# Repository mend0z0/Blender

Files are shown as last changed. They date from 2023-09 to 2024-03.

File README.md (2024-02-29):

## Latest update

``
Assembling the board, and working on the firmware...
``

# Blender

The Blender project's purpose is to extract digitalized sound characteristics like amplitude and frequency, which are transferring through the S/PDIF protocol, and display the amplitude of different frequencies by the dominant color of the input VGA received signal. So the base color will be determined by VGA input, and a spectrum of that color will be displayed over/on the DMX/WS2812 chip. Also, the specification of the sound will be displayed on an OLED, and the sound will be played by a chip that has an integrated DAC in it. The data to DAC will be transferred via the I2S protocol.

## Category

__Digital Signal Processing (DSP)__

## Features

- Battery Powered
- Can be installed in-line.
- On board speaker and WS2812 for troubleshooting.

## Technology

### Hardware

- **MCU:** STM32F446RCT6
- **Connection:** S/PDIF, VGA, DMX, I2S, Addressable LEDs (PWM)
- **PCB Layers:** 4Layer/s (None-controlled Impedance)
- **CAD:** KiCAD

### Firmware

- **OS:** FreeRTOS
- **Programming Language:** C
- **IDE:** STM32CubeIDE

### Mechanical

- **CAD:** Solid Edge
- **Manufacturing Method:** 3D Printing

## Block Diagram

SystemDesign

## Glamour Shots

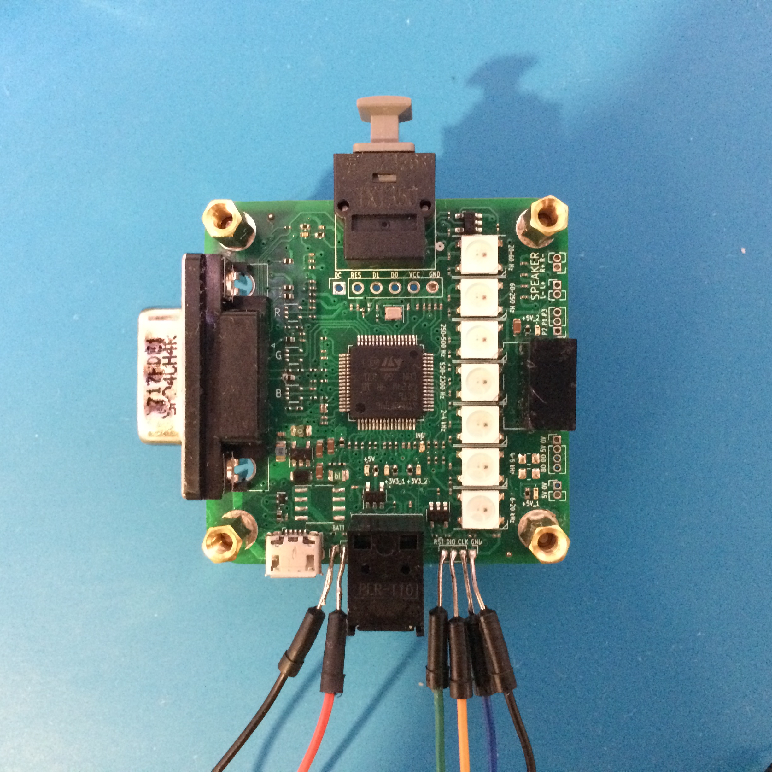
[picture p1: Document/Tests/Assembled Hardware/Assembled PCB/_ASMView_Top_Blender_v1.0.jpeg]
_ASMView_Top
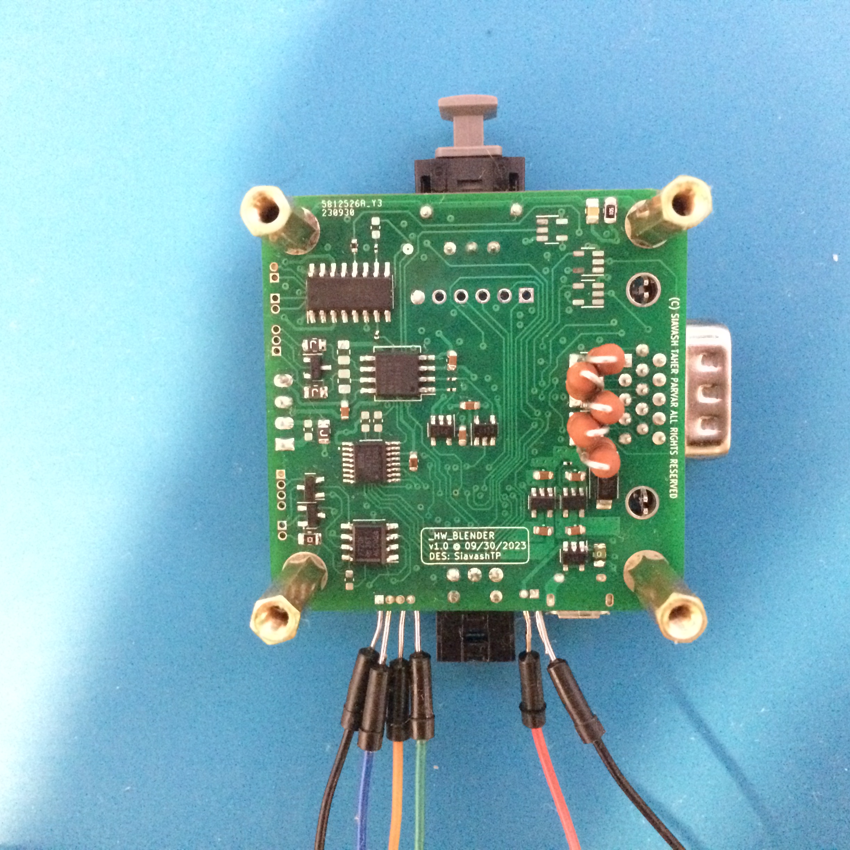
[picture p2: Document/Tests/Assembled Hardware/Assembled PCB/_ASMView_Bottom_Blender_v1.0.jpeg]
_ASMView_Bottom
|  |  | _3DModelView_Blender_v1-2024mmdd | _AppView_Blender_v1-2024mmdd |
|:--:| :--:| :--:| :--: |
| PCB Top View | PCB Bottom View | Enclosure View | Application View |

### Final Device

_BLENDER

## Demo

Not ready yet...

## Author

- [@Siavash Taher Parvar](https://www.linkedin.com/in/mend0z0)

## Support

- [Support Link](https://github.com/sponsors/mend0z0)

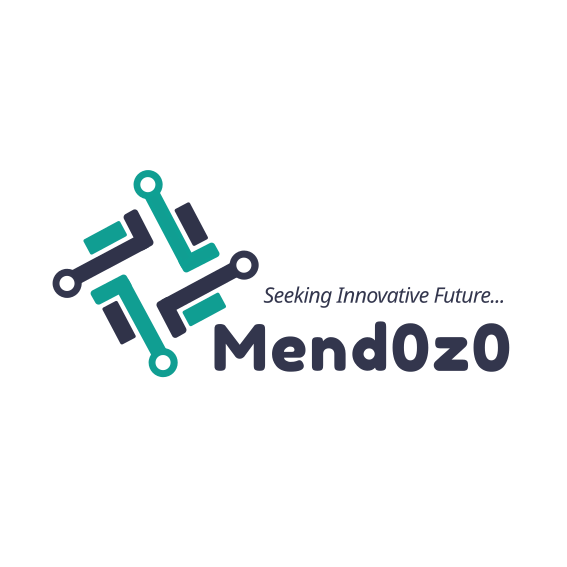
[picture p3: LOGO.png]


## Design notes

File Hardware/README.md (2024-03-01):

## _SUB_Hardware_Blender

- What is this board? This board is the main board which gets the inputs and runs some digital processing and will feed the the output devices.
- How will this board communicate? The current version will determine the output by the input signals.

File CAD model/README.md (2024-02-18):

# _SUB_Mechanical_Project

- What is this Mechanical Design? 
- Where would be located?

## Features

- __Material:__ PLA
- __Overall Dimensions:__
- __Manufacturing Method:__ 3D Printer

### Mechanical CAD View (Latest Version)

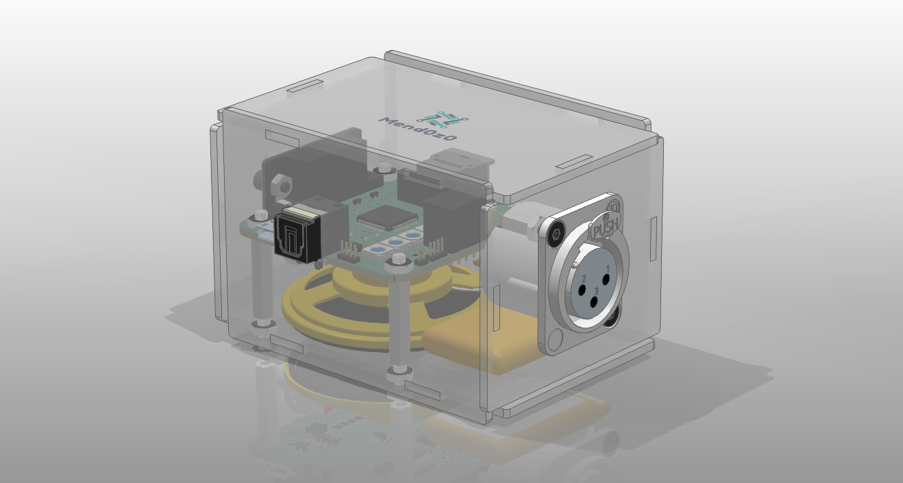
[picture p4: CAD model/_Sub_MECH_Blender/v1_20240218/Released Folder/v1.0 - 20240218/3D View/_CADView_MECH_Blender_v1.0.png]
_CADView_MECH_v1-20240218


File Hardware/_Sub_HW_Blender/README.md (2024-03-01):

## Version History Roadmap

- __v1_20230918 :__ 
	- It's the first version.

| 3D View - v1.0 | Features |
|:--:|:--:|
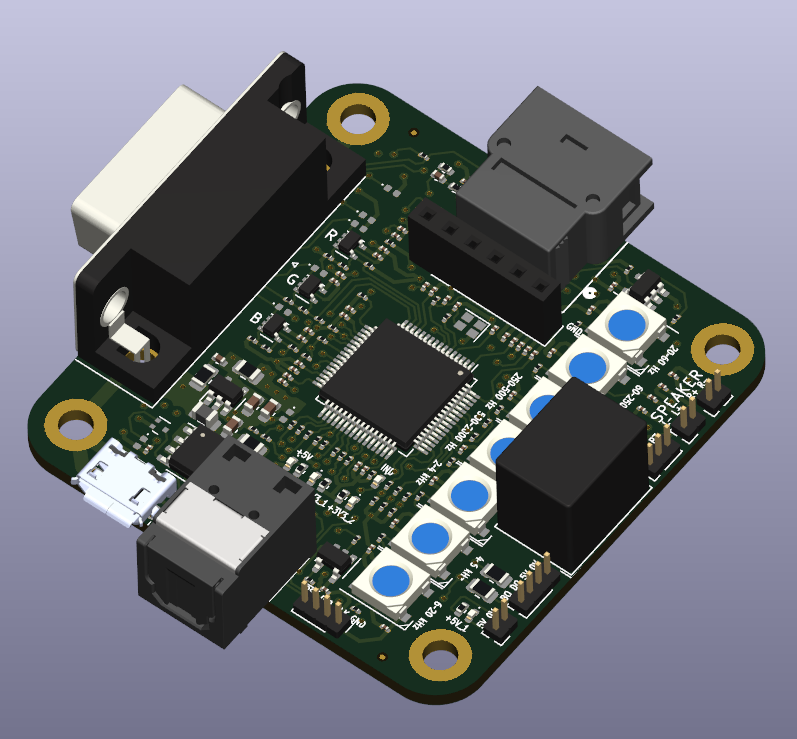
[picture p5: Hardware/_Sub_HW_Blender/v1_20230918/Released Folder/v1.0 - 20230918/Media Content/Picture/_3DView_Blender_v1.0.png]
_3DView_v1_20230918
|  | <br><P align="left">__MCU :__ STM32F446RCT6</br><br align="left">__Inputs :__ VGA Input, S/PDIF</br><br align="left">__Outputs :__ DMX, WS2812, SPEAKER, Display (OLED)</br><br align="left">__Board Osc. Freq. :__ 160 MHz</br><br align="left">__Working Voltage :__ 3.3 VDC </br><br align="left">__Current Consumption :__  TBD</br><br align="left">__Board Dimensions :__ 50*50 mm</br> |

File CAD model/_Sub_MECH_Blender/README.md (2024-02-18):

# Version History

A brief description of this version history belongs to what project

## Roadmap

- __v1_20240218 :__ It's the first version.

### Mechanical CAD View (Latest Release)

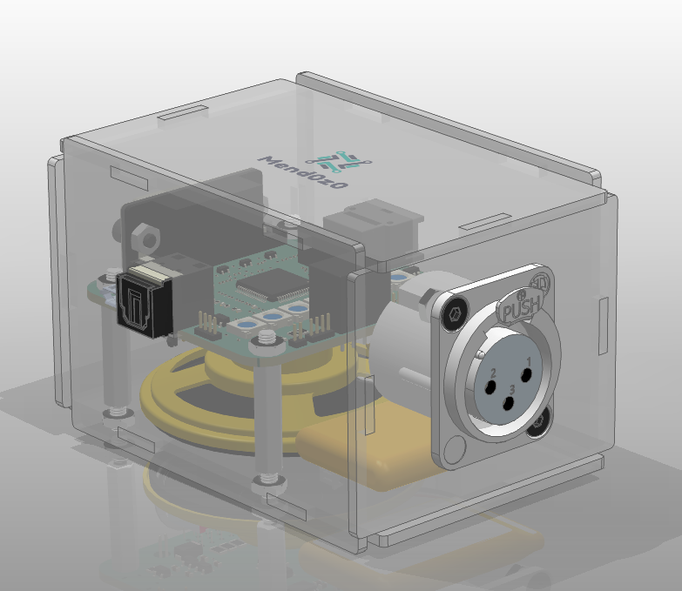
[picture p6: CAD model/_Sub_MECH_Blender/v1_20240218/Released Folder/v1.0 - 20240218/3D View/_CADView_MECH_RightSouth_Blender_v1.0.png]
_CADView_MECH_RightSouth_Blender_v1_20240218


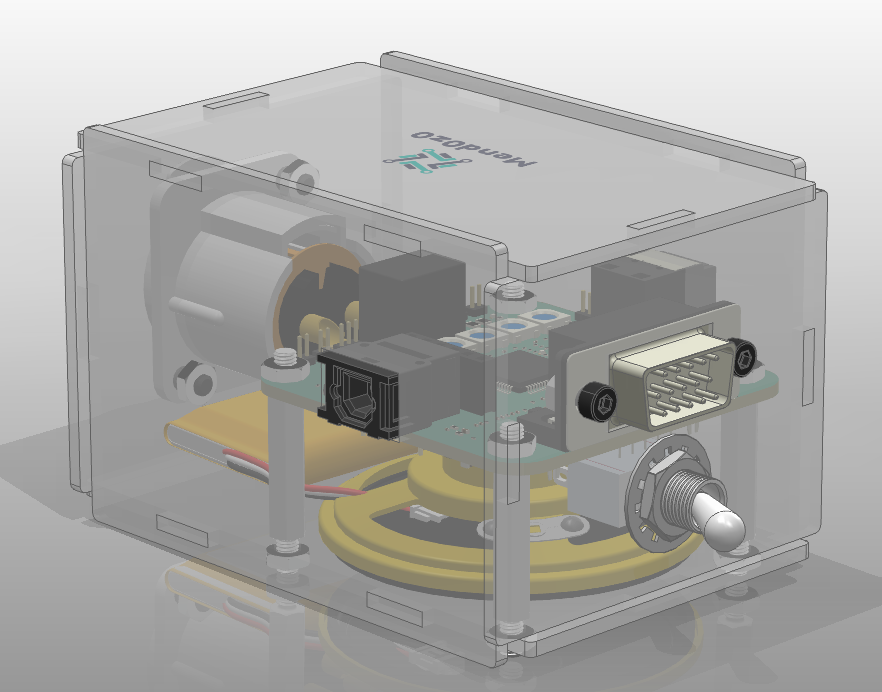
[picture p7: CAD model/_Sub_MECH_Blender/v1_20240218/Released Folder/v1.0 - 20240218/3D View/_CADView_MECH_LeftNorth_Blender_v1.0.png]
_CADView_MECH_Blender_LeftNorth_v1_20240218


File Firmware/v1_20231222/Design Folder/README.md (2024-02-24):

# TODO List

Blender firmware project todo list.

## Tasks

- #### MUST DO (List the works that proper working of project depends on these tasks):
    - Drawing peripheral functions block diagram (CLK, GPIO, TIMER 0, TIMER 1, TIMER 2, TIMER 3, I2C, DMA, RTC, SPDIF, I2S, ADC, UART, WDT)
    - 
    - Drawing each module/device API/Init functions block diagram (Ind LED, SSD1306, Toslink, WS2812, DMX, VGA, PAM8003, PCM1754)
    - Writing C code for the drawn block diagram
    - Writing C code for the ISR
    - Writing C code for the modules/devices
    - Drawing a test scenario for connected modules/devices
    - Writing C code the test scenario block diagram
    - Drawing block diagram for main super-loop
    - Writing C code for the main super-loop block diagram
    - 
    - 
    - Doing UART + DMA driver
    - Doing DMX
    - Doing TIM3 + DMA
    - Doing WS2812
    - Doing I2C + DMA
    - Doing SSD1306 Driver
    - Doing FreeRTOS
    - 
    - 
    - 
    - 
    - 
    -
    - 
- #### Important (List the works that efficient and optimized functionality of project depends on these tasks):
    - Configuring TIM5 for reading system clock frequency and displaying on OLED (Next revision)
    -
    - 
- #### General (List tasks that are good to be done but the functionality of project doesn't depend on these):
    - 
    -
    -

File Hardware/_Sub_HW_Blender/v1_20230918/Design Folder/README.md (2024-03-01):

## TODO list

Blender hardware project v1 todo list.

## Tasks

- #### MUST DO (List the works that proper working of project depends on these tasks):
    - Correcting the power ports labels.?
    - Labeling correction (Correcting that @ shit in the info label on the PCB). (Next revision)
    - Checking circuitry and adding information
    - Adding Mechanical parts (Wire, XLR connector, inline connector for ws2812, OLED, some standoffs, screws, and enclosure, 2 x speaker).
    - Doing the Power sequence analysis
    - Exporting output files
    - Adding info to Coverpage
    - Correcting the information for each page
    - 
    - Very important, changing the MOSFET part number to SI4435FDY-T1-GE3 (https://www.digikey.ca/en/products/detail/vishay-siliconix/SI4435FDY-T1-GE3/7566600). (Next revision)
    - Very important, changing the MOSFET gate circuit to a pulldown resistor and a PNP transistor. (Next revision)
    - Modifying prog pins according to the programmer. (Next revision)
    - Placing the logo in a better and visible spot. (Next revision)
    - Remove all the resistors for WS2812 (or make it like 10ohm or 0ohm)
    - 
    - 
    - 
- #### Important (List the works that efficient and optimized functionality of project depends on these tasks):
    - Sizing up the packages to 0603. (Next revision)
    - Adding the missing 3D parts. (Next revision)
    - Adding on/off switch. (Next revision)
    - Adding test points for voltages. (Next revision)
    -
    - 
- #### General (List tasks that are good to be done but the functionality of project doesn't depend on these):
    - 
    -
    -

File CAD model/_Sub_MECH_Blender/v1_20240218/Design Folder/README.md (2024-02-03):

# TODO list

A brief description of this todo list belongs to what project

## Tasks

- #### MUST to DO (List the works that proper working of project depends on these tasks):
    - Add a screw for
    - Add a USB slot
    - Add a power button (push button)
    - Add the logo in a way that would be engraved... (looking for how to add a picture as an object so I can give it depth
    - Add a slot for WS2812
    - Opening an output folder (one output for laser cut)
    - Add a tolerance to the openings
    - Make the edges curvy..
    - adding a switch to enclosure
    - 
    - 
    - 
- #### Important (List the works that efficient and optimized functionality of project depends on these tasks):
    - 
    -
    - 
- #### General (List tasks that are good to be done but the functionality of project doesn't depend on these):
    - 
    -
    -

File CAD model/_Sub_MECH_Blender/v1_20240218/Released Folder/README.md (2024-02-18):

# Revision History

A brief description of this revision history belongs to what project

## Roadmap

- #### __v1.0_20240218 :__ 
    - List the changes or modification that have been applied in this revision.

### Mechanical CAD View

_CADView_MECH_v1.0_20240218

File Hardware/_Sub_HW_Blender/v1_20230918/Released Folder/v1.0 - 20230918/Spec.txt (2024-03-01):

#Board Spec
- __MCU :__ STM32F446RCT6
- __Inputs :__ VGA Input, S/PDIF
- __Outputs :__ DMX, WS2812, SPEAKER, Display (OLED) 
- __Board Osc. Freq. :__ 160 MHz
- __Working Voltage :__ 3.3 VDC
- __Current Consumption :__  TBD

#Board Statistics
- __Component Total: 217
- __Total Pad: 858
- __Total Vias: 146 
- __Board Layers: 4 Layers (Non-impedance Controlled)
- __Board Dimensions :__ 49.66 * 49.66 mm2

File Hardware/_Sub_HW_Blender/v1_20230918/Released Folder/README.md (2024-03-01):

## Revision History Roadmap

- #### __v1.0_20230918 :__ 
	The first release.

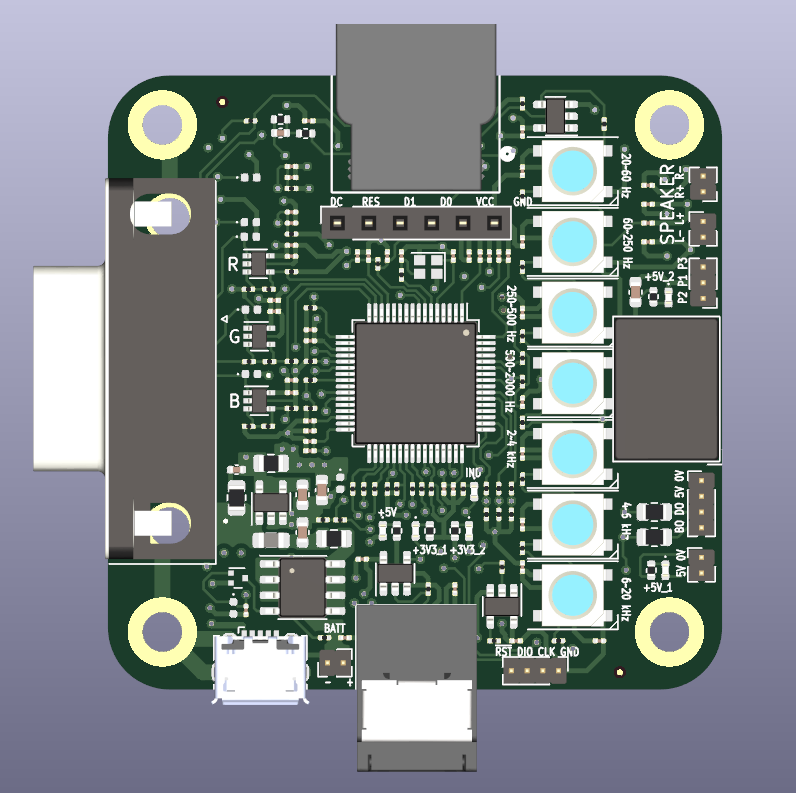
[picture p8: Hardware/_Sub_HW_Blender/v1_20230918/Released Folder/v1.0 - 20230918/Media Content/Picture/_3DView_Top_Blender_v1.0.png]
_3DView_Top_Blender_v1.0
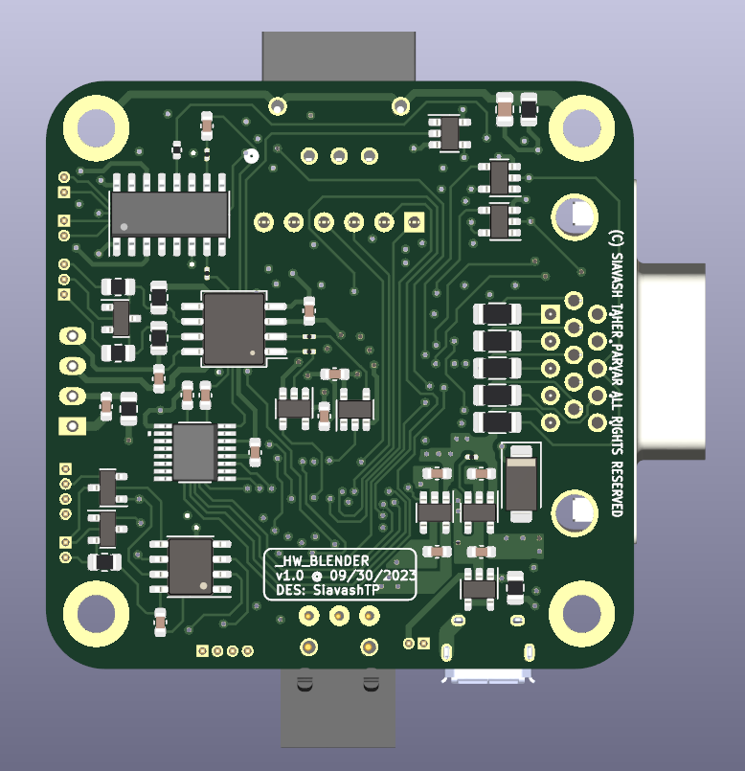
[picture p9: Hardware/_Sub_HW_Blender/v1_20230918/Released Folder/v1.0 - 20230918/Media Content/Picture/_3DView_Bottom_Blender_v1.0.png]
_3DView_Bottom_Blender_v1.0
| Hardware | |  |
|:--:|:--:|:--:|
| Block Diagram | Top Layer | Bottom Layer |

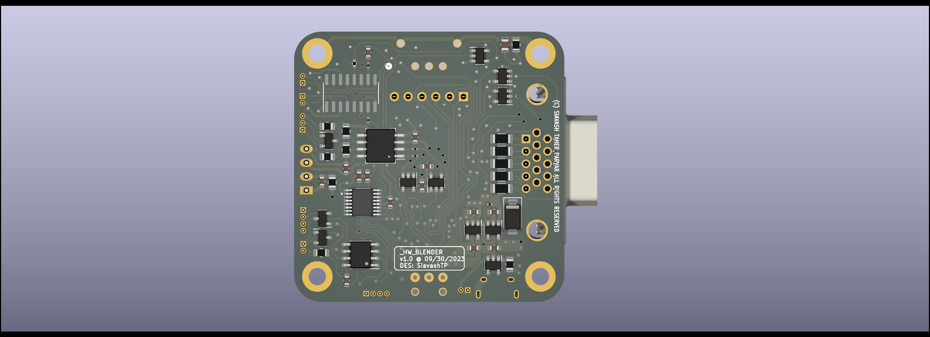
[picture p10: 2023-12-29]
Hardware/_Sub_HW_Blender/v1_20230918/Design Folder/_HW_Blender/Output files/3D View/_3DView_Bottom_Blender_v1.0.png

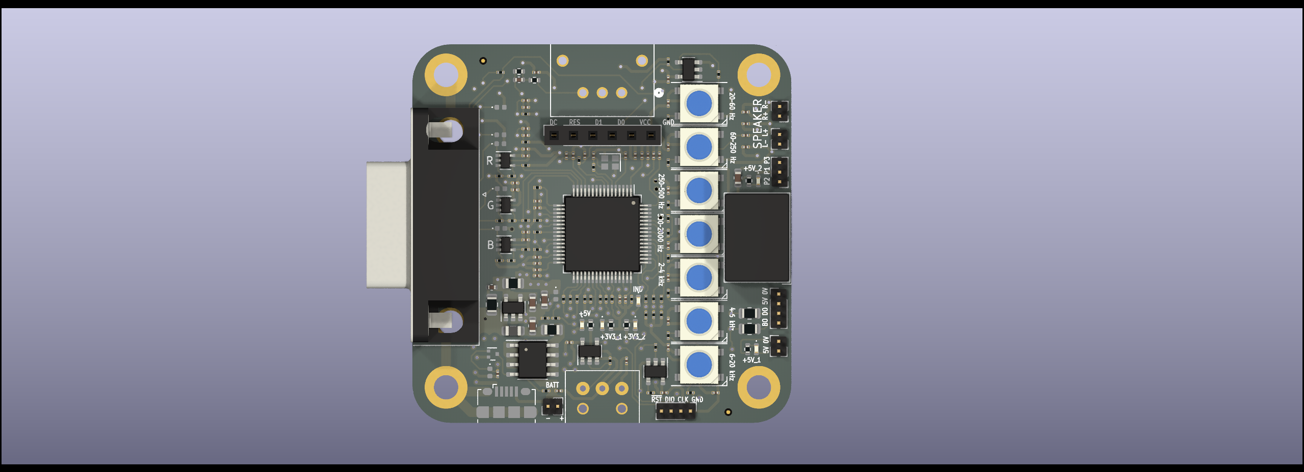
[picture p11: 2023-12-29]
Hardware/_Sub_HW_Blender/v1_20230918/Design Folder/_HW_Blender/Output files/3D View/_3DView_Top_Blender_v1.0.png

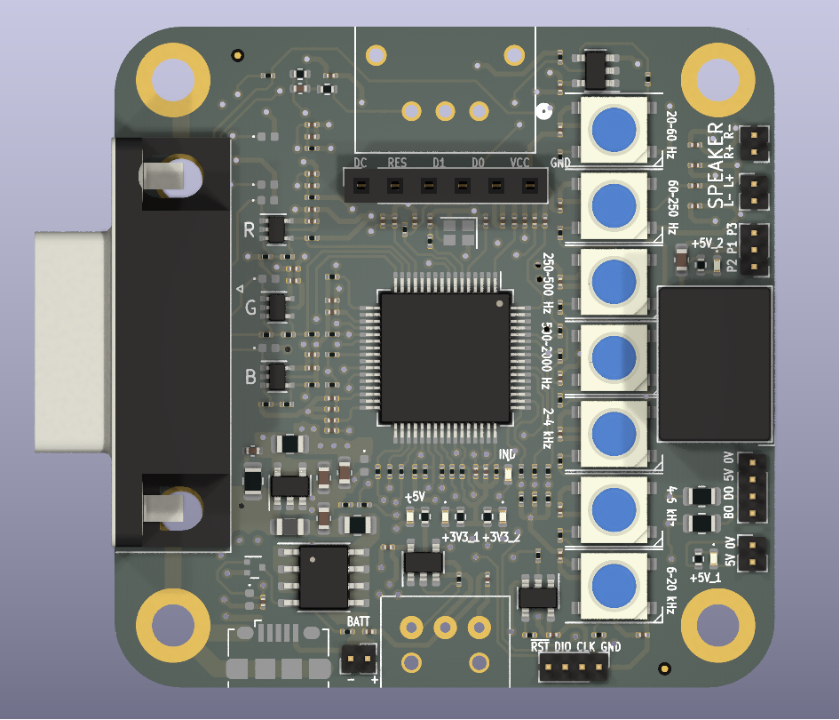
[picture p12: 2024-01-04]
Hardware/_Sub_HW_Blender/v1_20230918/Design Folder/_HW_Blender/Output files/3D View/_3DView_Top_Blender_v1.0 - Copy.png

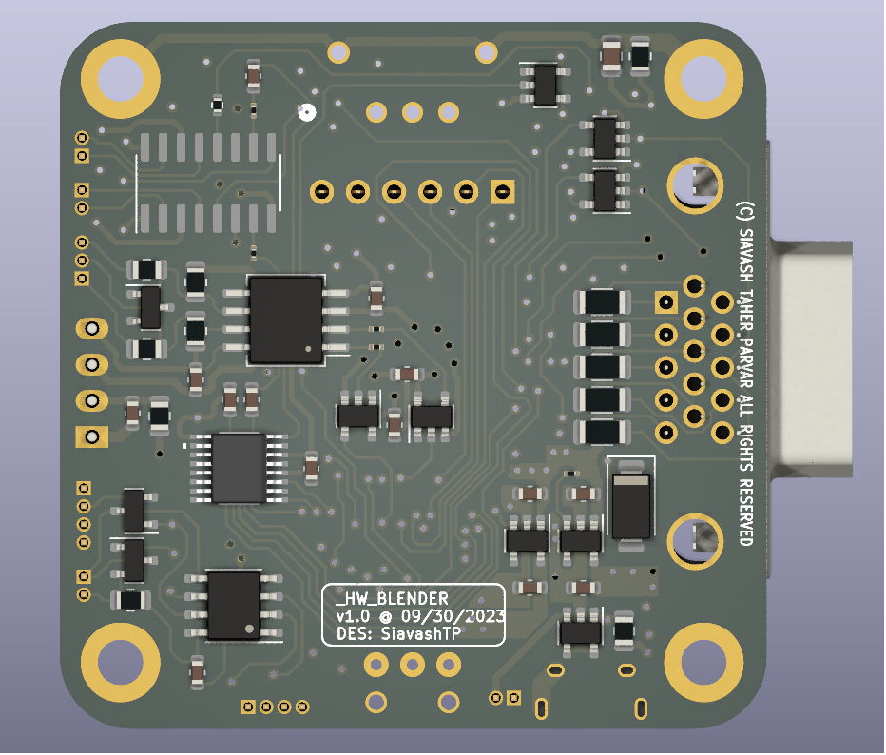
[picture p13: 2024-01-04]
Hardware/_Sub_HW_Blender/v1_20230918/Design Folder/_HW_Blender/Output files/3D View/_3DView_Bottom_Blender_v1.0 - Copy.png

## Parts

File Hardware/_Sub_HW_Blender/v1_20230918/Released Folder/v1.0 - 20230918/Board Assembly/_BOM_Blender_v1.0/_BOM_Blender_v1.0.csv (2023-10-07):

Id | Designator | Footprint | Quantity | Designation | Supplier and ref
1 | R615,R1008,R701,R1003,R1005 | R_0402_1005Metric | 5 | 470R_1/16W
2 | X301 | Crystal_SMD_2016-4Pin_2.0x1.6mm | 1 | 16MHz/10ppm
3 | R812,R814,R901,R815,R813,R902,R403,R1002 | R_0201_0603Metric | 8 | 4K7R_1/20W
4 | R506,R509,R303 | R_0201_0603Metric | 3 | 49R9_1/20W
5 | R611,R612 | R_0805_2012Metric | 2 | 1KR_1/8W
6 | R1302,R1201,R1202,R1301,R1402,R1401 | R_0201_0603Metric | 6 | 47KR_1/20W
7 | J501 | DSUB-15-HD_Male_Horizontal_P2.29x1.98mm_EdgePinOffset3.03mm_Housed_MountingHolesOffset4.94mm | 1 | DE-15_MALE_RA
8 | C1401,C808,C1201,C609,C601,C604,C1301,C607,C501,C805,C309,C806,C605,C608,C603,C611,C308,C503,C606,C602 | C_0201_0603Metric | 20 | 2u2F/6V3
9 | D1002,D503,D505,D502,D1003,D501,D504 | D_0402_1005Metric | 7 | GG040205100N2P
10 | J1002 | USB_Micro-B_Amphenol_10118194_Horizontal | 1 | MICRO B USB_RA
11 | C1402,C305,C311,C502,C403,C1202,C402,C1302,C307,C317,C315,C404,C504,C313 | C_0201_0603Metric | 14 | 100nF/6V3
12 | D604,D603,D605,D601,D607,D606,D602 | LED_WS2812B_PLCC4_5.0x5.0mm_P3.2mm | 7 | WS2812B
13 | J901 | PinSocket_1x06_P2.54mm_Vertical | 1 | RCPT_6POS_2.54MM_VERT
14 | C303,C302 | C_0201_0603Metric | 2 | 12pF/50V
15 | R607,R810,R806,R804,R903,R606,R808,R1006,R803,R614,R608,R603,R610,R605,R602,R601,R304,R613,R904,R809,R811,R807,R704,R705,R805 | R_0201_0603Metric | 25 | 100R_1/20W
16 | J301,J602 | PinHeader_1x04_P1.27mm_Vertical | 2 | RCPT_4POS_1.27MM
17 | U301 | LQFP-64_10x10mm_P0.5mm | 1 | STM32F446RCT6TR
18 | J402 | TOTX1350_TOS | 1 | TOTX1350(F)
19 | R604,R404,R801,R1007,R504,R1203,R1403,R702,R302,R507,R1303,R301,R1004 | R_0201_0603Metric | 13 | 10KR_1/20W
20 | C306,C310,C312,C1006,C807,C1005,C314,C304,C316,C301,C901 | C_0201_0603Metric | 11 | 1uF/6V3
21 | LED1002,LED1003 | LED_0402_1005Metric | 2 | AMBER
22 | J701 | PinHeader_1x03_P1.27mm_Vertical | 1 | RCPT_3POS_1.27MM
23 | C401,C1001 | C_0402_1005Metric | 2 | 680pF_50V
24 | C1003,C1002,C702,C1004,C801,C1009,C610,C1007,C1010,C804,C1008,C803,C802,C705,C701,C703,C704,C706 | C_0603_1608Metric | 18 | 10uF/16V
25 | LED601,LED1001,LED701 | LED_0402_1005Metric | 3 | GREEN
26 | U701 | Converter_DCDC_RECOM_R-78S-0.1_THT | 1 | 1S4E_0505S1.5U
27 | J1001,J802,J601,J801 | PinHeader_1x02_P1.27mm_Vertical | 4 | MHDR_2POS_1.27MM_VERT
28 | Q1002 | SOT-723 | 1 | RN1130MFV,L3F
29 | R401 | R_0402_1005Metric | 1 | 330R_1/16W
30 | LED301 | LED_0402_1005Metric | 1 | RED
31 | U1301,U1201,U1401 | SOT-353_SC-70-5 | 3 | MIC920YC5-TR
32 | R1001 | R_0805_2012Metric | 1 | 4R7_1/4W
33 | U603,U401,U601,U702,U501,U402,U502,U705 | SOT-23-5 | 8 | SN74LVC1G17DBVR
34 | RV1001,RV1002 | Fuse_0805_2012Metric | 2 | PTC_500mA
35 | U1001 | SOT-23-5 | 1 | TPS613222ADBVR
36 | J401 | PLR237T10BK | 1 | PLR237/T10BK
37 | F1001 | Fuse_0805_2012Metric | 1 | 0ZCK0100FF2E
38 | R402,R802 | R_0402_1005Metric | 2 | 100R_1/10W
39 | L1001 | L_0805_2012Metric | 1 | 2u2H_2A
40 | FD1102,FD1101 | Fiducial_0.5mm_Mask1mm | 2 | ~
41 | Q1001 | SO-8_3.9x4.9mm_P1.27mm | 1 | SI4455DY-T1-GE3
42 | U703 | SOT-23 | 1 | CDSOT23-SM712
43 | R501,R502,R508,R503,R505 | R_1206_3216Metric | 5 | 75R_2W
44 | D1001 | D_SMA | 1 | SK510A-LTP
45 | R706,R703 | R_0805_2012Metric | 2 | 680R_1/8W
46 | F703,F702,F701 | Fuse_0805_2012Metric | 3 | 0805L010/24YR
47 | U1003 | SOT-23-5 | 1 | MCP73811T-420I/OT
48 | U605,U604 | SOT-23 | 2 | DLPT05A-7
49 | C1101 | C_0805_2012Metric | 1 | 1nF_500V
50 | U801 | SOP-16_3.9x9.9mm_P1.27mm | 1 | PAM8003DR
51 | R609 | R_0805_2012Metric | 1 | 100R_1/8W
52 | U1002,U1004 | SOT-23-5 | 2 | TLV74033PDBVR
53 | U802 | DBQ16 | 1 | PCM1754DBQR
54 | U602 | SOIC-8_3.9x4.9mm_P1.27mm | 1 | ISO7720FDR
55 | R1101 | R_0805_2012Metric | 1 | 1MR_1/2W
56 | U704 | SO-8_5.3x6.2mm_P1.27mm | 1 | MAX22028AWA+

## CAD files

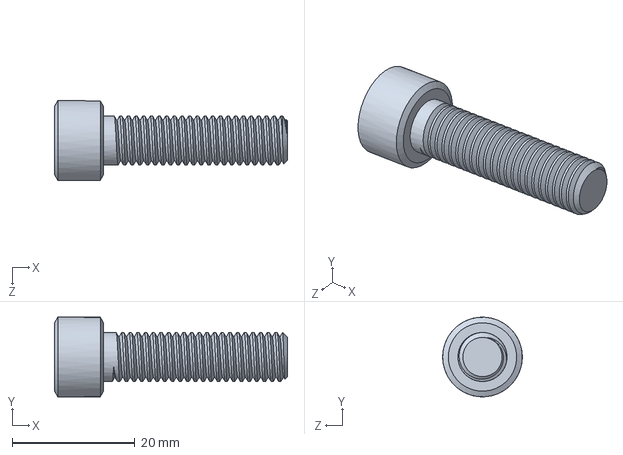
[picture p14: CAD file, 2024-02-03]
CAD model/_Sub_MECH_Blender/v1_20240218/Design Folder/_MECH_Blender/Parts/TORNILLO DIN-912-2014.SLDPRT
38.0 x 13.0 x 13.0 mm

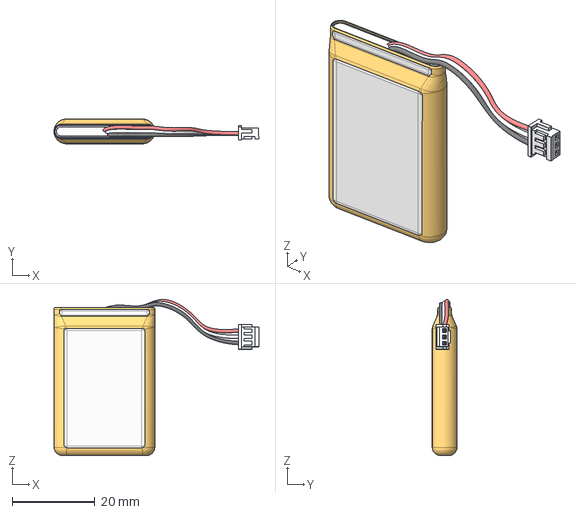
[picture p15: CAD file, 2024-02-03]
CAD model/_Sub_MECH_Blender/v1_20240218/Design Folder/_MECH_Blender/STEP Files/3.7v li-ion 500mah Battery.step
49.6 x 6.05 x 37.8 mm

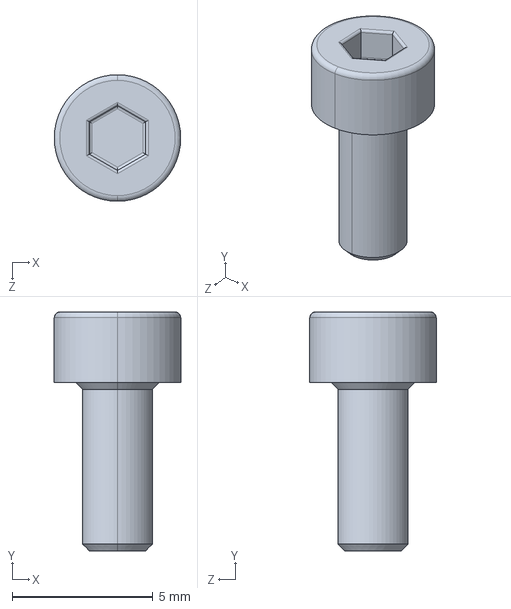
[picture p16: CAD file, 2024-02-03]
CAD model/_Sub_MECH_Blender/v1_20240218/Design Folder/_MECH_Blender/STEP Files/User Library-Dinp912.step
4.50 x 8.50 x 4.50 mm

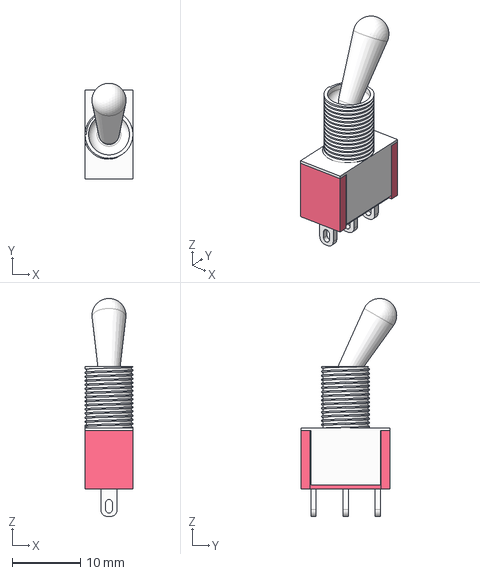
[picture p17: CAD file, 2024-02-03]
CAD model/_Sub_MECH_Blender/v1_20240218/Design Folder/_MECH_Blender/STEP Files/toggle switch.step
7.00 x 14.0 x 32.0 mm

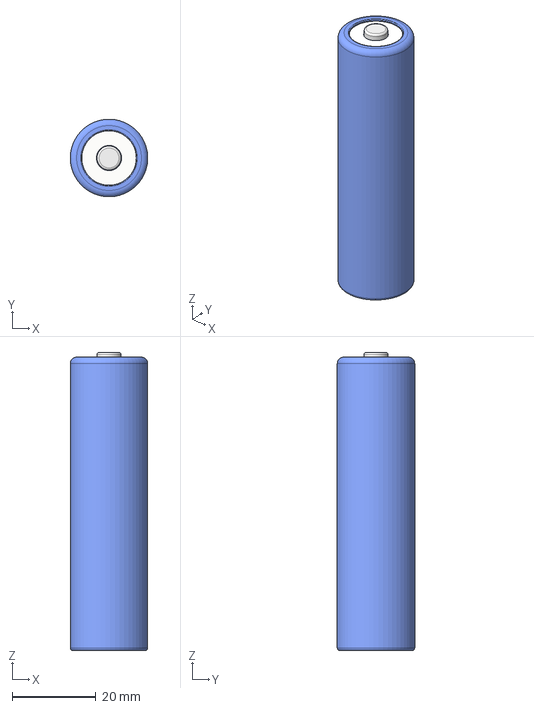
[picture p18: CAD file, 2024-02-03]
CAD model/_Sub_MECH_Blender/v1_20240218/Design Folder/_MECH_Blender/STEP Files/Profuse - 18650.step
18.5 x 18.5 x 71.1 mm

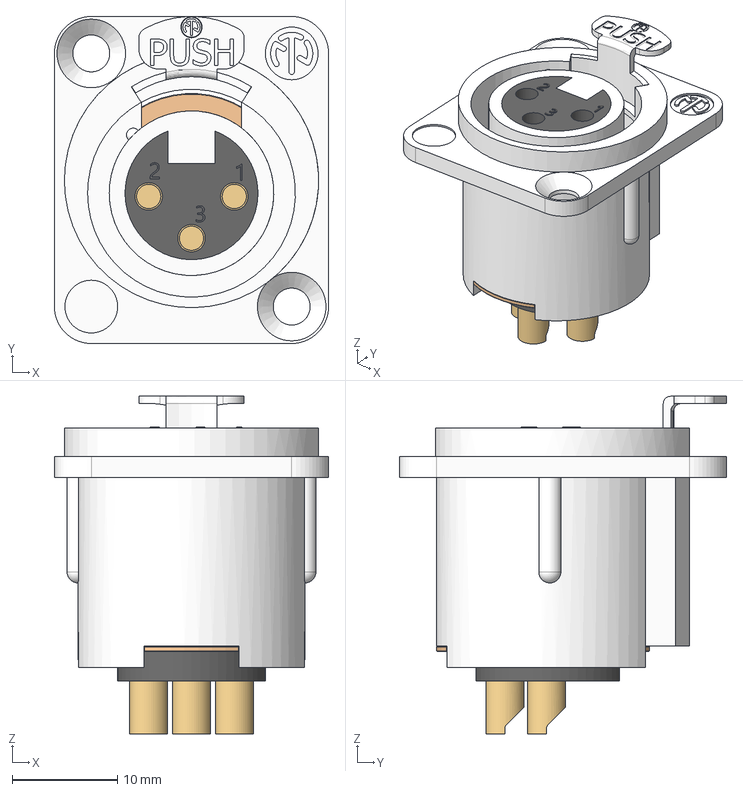
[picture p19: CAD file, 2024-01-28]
CAD model/_Sub_MECH_Blender/v1_20240218/Design Folder/_MECH_Blender/STEP Files/NC3FD-LX.stp
26.0 x 31.0 x 32.0 mm
5-POLE
BACK LOCK
PUSH PIN
PIN x 3

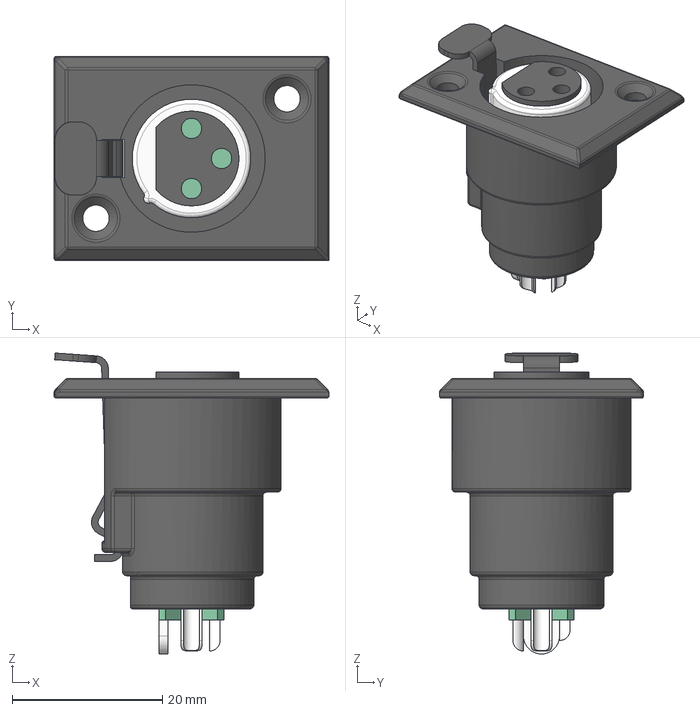
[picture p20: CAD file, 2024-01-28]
CAD model/_Sub_MECH_Blender/v1_20240218/Design Folder/_MECH_Blender/STEP Files/Connector, XLR3, Female, Chassis - Switchcraft-D3FB.stp
36.5 x 27.1 x 40.0 mm

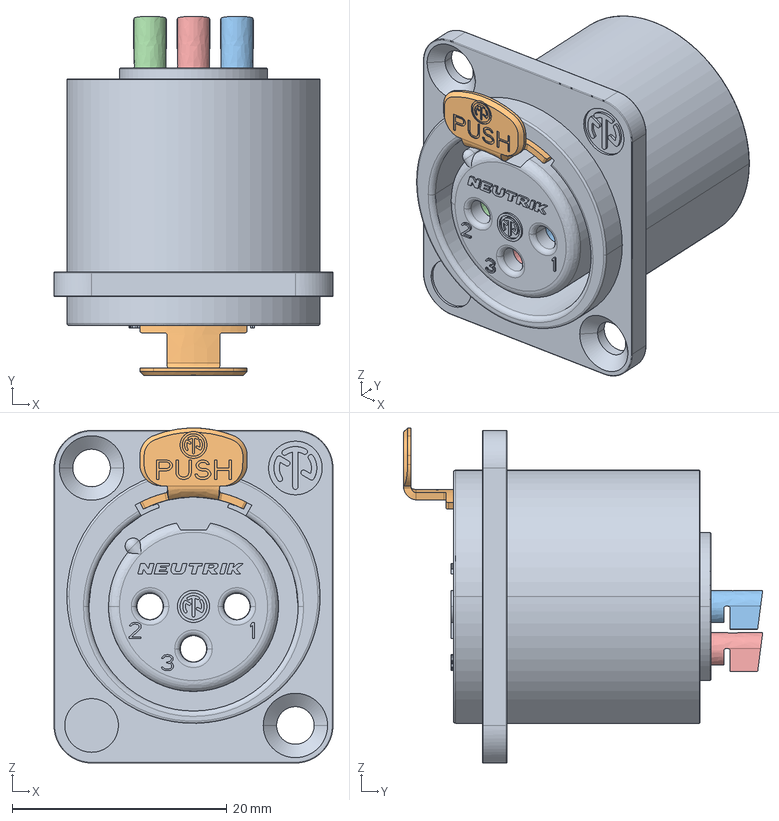
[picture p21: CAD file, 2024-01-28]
CAD model/_Sub_MECH_Blender/v1_20240218/Design Folder/_MECH_Blender/STEP Files/NC3FD-LX_01-GC-STEP.stp
26.0 x 33.5 x 31.2 mm

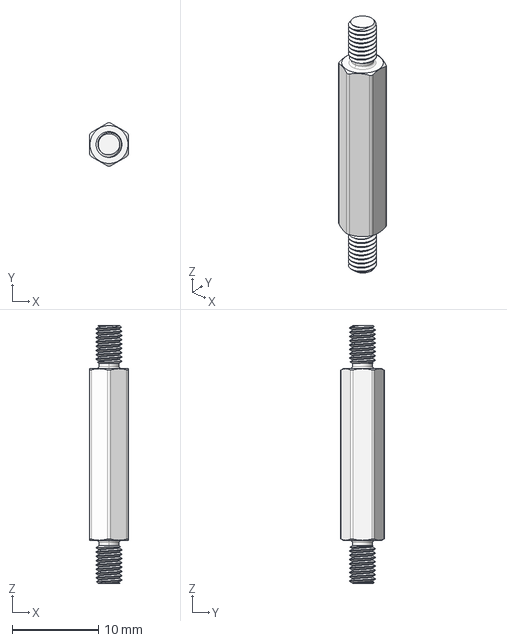
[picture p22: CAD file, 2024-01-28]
CAD model/_Sub_MECH_Blender/v1_20240218/Design Folder/_MECH_Blender/STEP Files/Standoff M3 M-M H 20mm.stp
4.50 x 5.08 x 30.0 mm

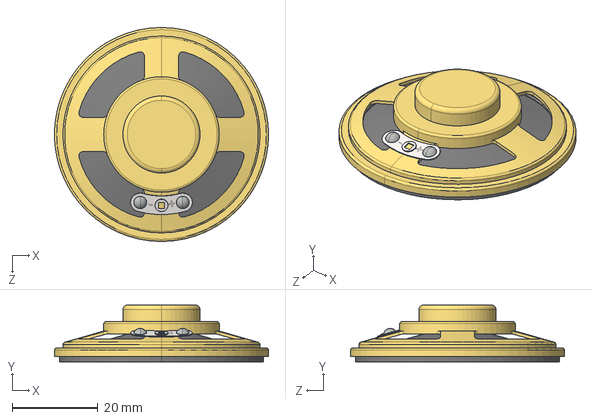
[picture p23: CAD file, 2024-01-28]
CAD model/_Sub_MECH_Blender/v1_20240218/Design Folder/_MECH_Blender/STEP Files/Speaker, dia 50mm.STEP
50.0 x 13.3 x 50.0 mm

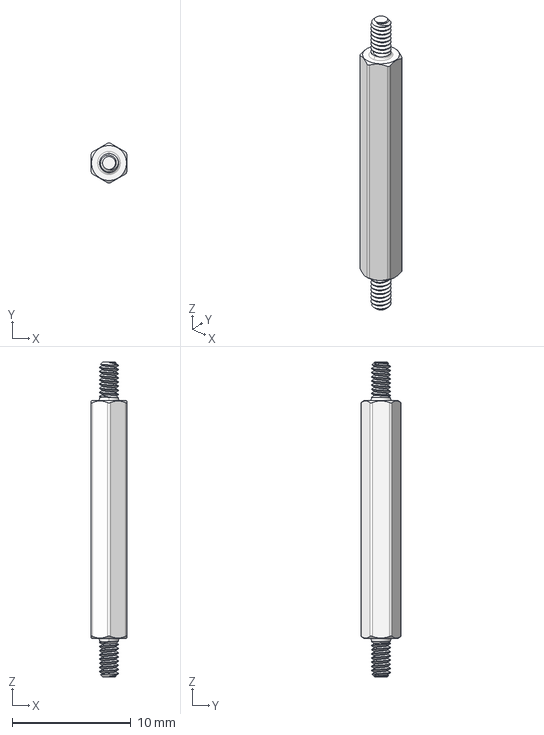
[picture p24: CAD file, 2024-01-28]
CAD model/_Sub_MECH_Blender/v1_20240218/Design Folder/_MECH_Blender/STEP Files/Standoff M1.6 M-M H 20mm.stp
3.00 x 3.39 x 26.5 mm

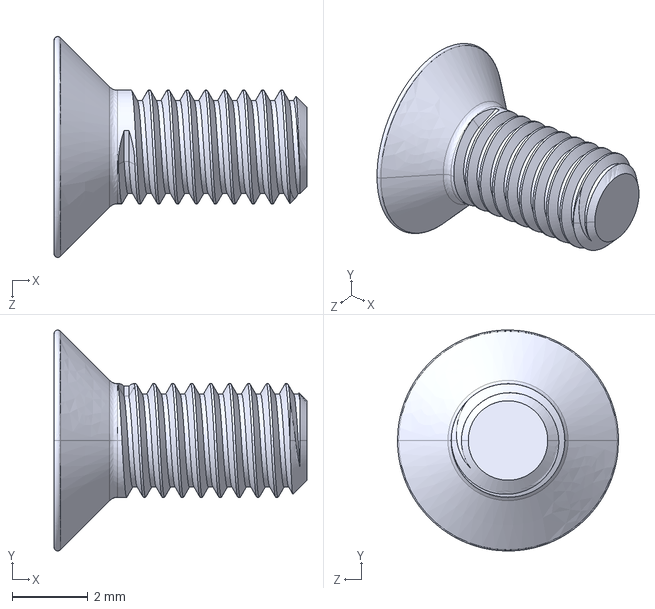
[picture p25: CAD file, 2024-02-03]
CAD model/_Sub_MECH_Blender/v1_20240218/Design Folder/_MECH_Blender/Parts/M3_Countersunk_Screw_5.IGS
6.68 x 5.84 x 5.84 mm

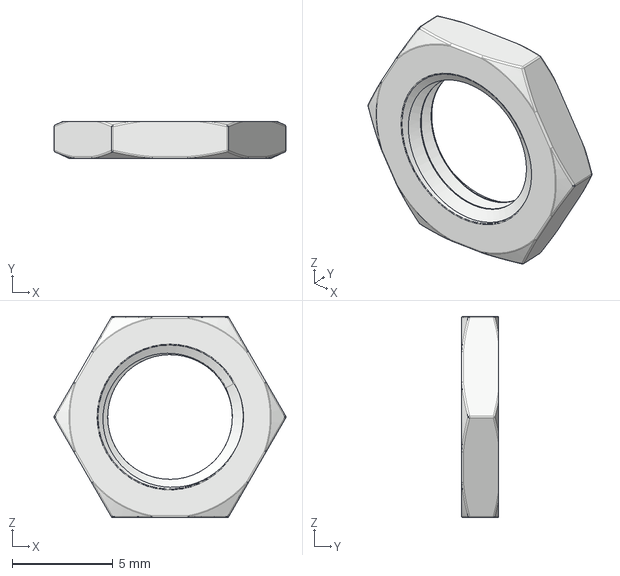
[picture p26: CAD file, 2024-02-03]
CAD model/_Sub_MECH_Blender/v1_20240218/Design Folder/_MECH_Blender/STEP Files/Nut M7x075.stp
11.5 x 1.85 x 10.0 mm

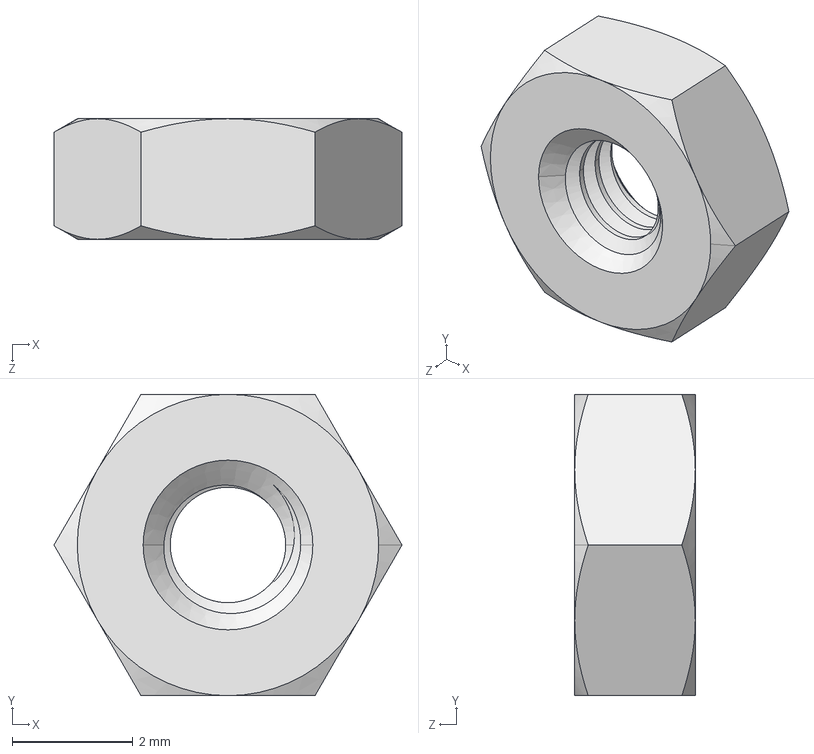
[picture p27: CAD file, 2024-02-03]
CAD model/_Sub_MECH_Blender/v1_20240218/Design Folder/_MECH_Blender/STEP Files/M2.5 Nut.STEP
5.77 x 5.00 x 2.00 mm

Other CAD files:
CAD model/_Sub_MECH_Blender/v1_20240218/Design Folder/_MECH_Blender/Parts/Connector, XLR3, Female, Chassis - Switchcraft-D3FB.igs
CAD model/_Sub_MECH_Blender/v1_20240218/Design Folder/_MECH_Blender/Parts/Connector, XLR3, Female, Chassis - Switchcraft-D3FB.x_t
CAD model/_Sub_MECH_Blender/v1_20240218/Design Folder/_MECH_Blender/Parts/m3 lock nut.prt

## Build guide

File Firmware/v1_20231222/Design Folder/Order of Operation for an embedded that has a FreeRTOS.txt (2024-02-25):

1- Init power
2- init CLOCK & systick
3- Init GPIOs (just direction)
4- Enable global interrupts
4- Init default task (a blinking LED)
5- Init other tasks... (Enable the interrupt in the tasks so each task will init its own peripheral)
6- Run scheduler

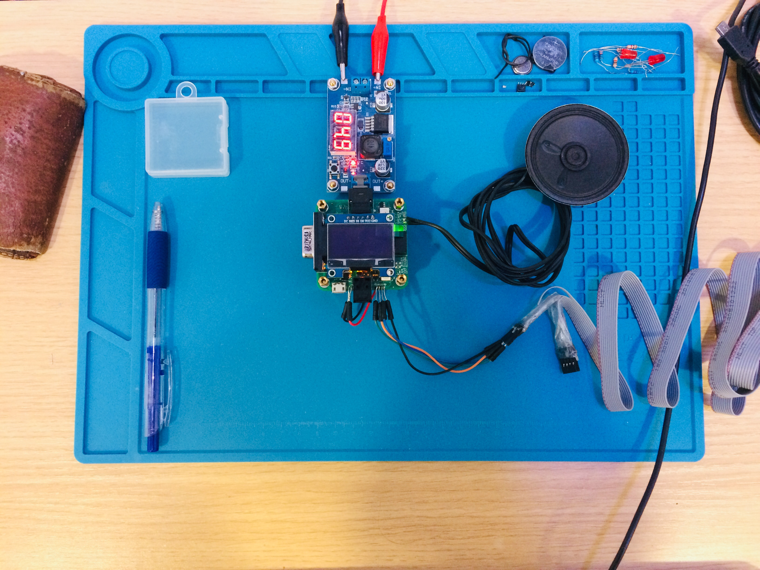
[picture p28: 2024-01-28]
Document/Tests/Assembled Hardware/Assembled PCB/96124B41-6FE8-4BA1-9D16-8A02EC38EB6A.jpeg

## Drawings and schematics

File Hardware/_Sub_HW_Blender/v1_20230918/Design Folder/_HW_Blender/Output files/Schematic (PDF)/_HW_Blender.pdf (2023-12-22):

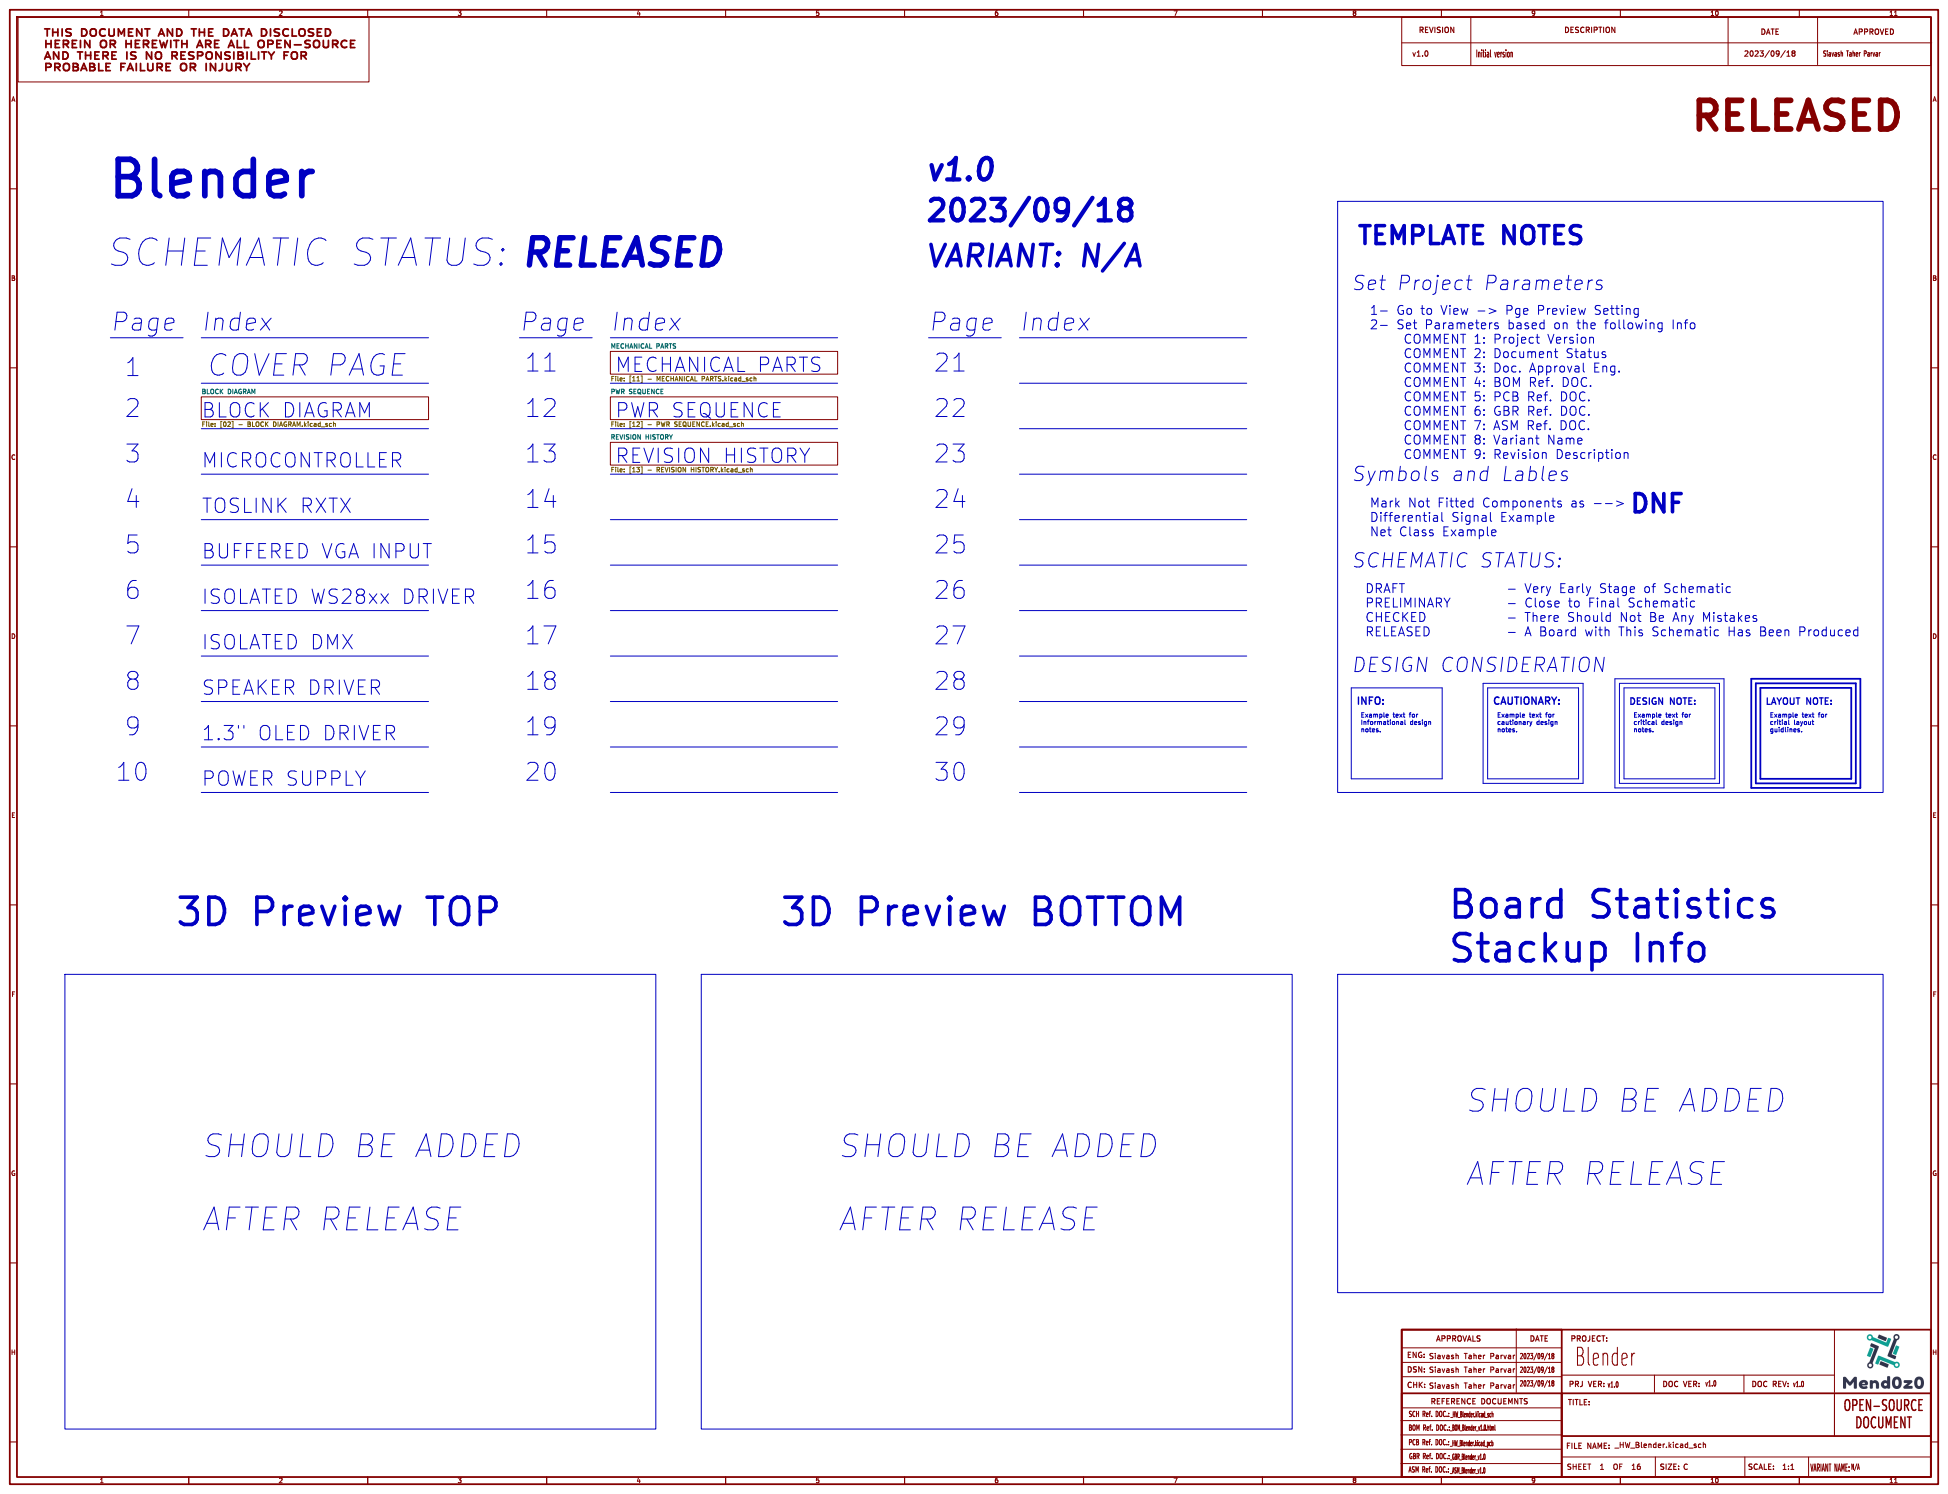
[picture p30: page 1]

1- Go to View -> Pge Preview Setting
Symbols and Lables

File: [11] - MECHANICAL PARTS.kicad_sch REVISION HISTORY
File: [13] - REVISION HISTORY.kicad_sch PWR SEQUENCE
PWR SEQUENCE

Mark Not Fitted Components as -->
Net Class Example
SCHEMATIC STATUS:

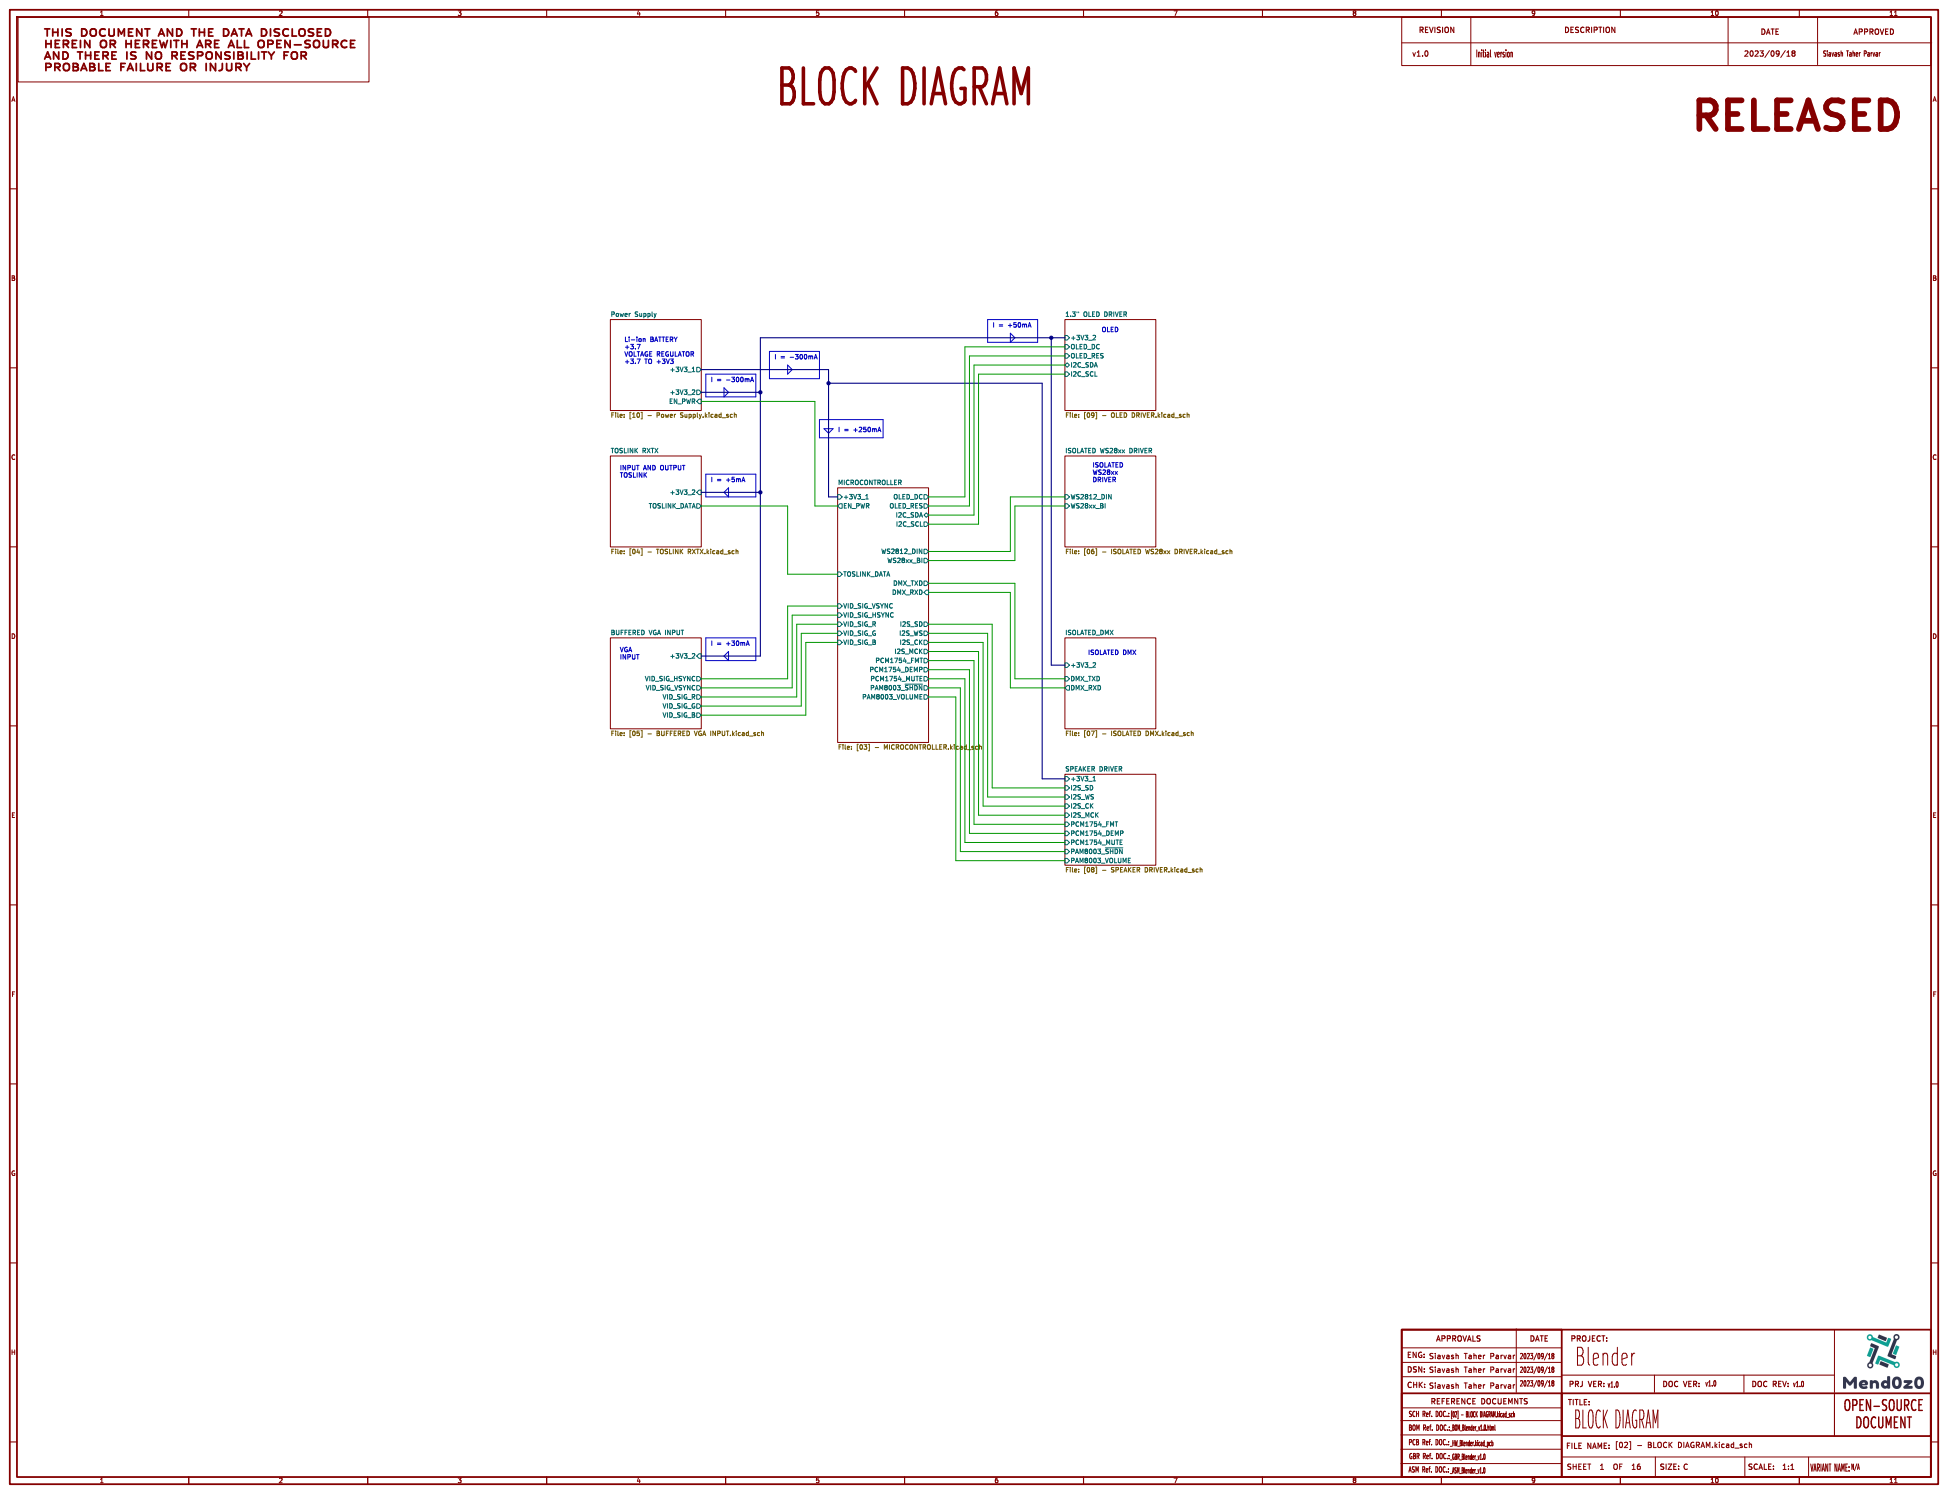
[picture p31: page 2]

+3V3_2 +3V3_1 Power Supply File: [10] - Power Supply.kicad_sch

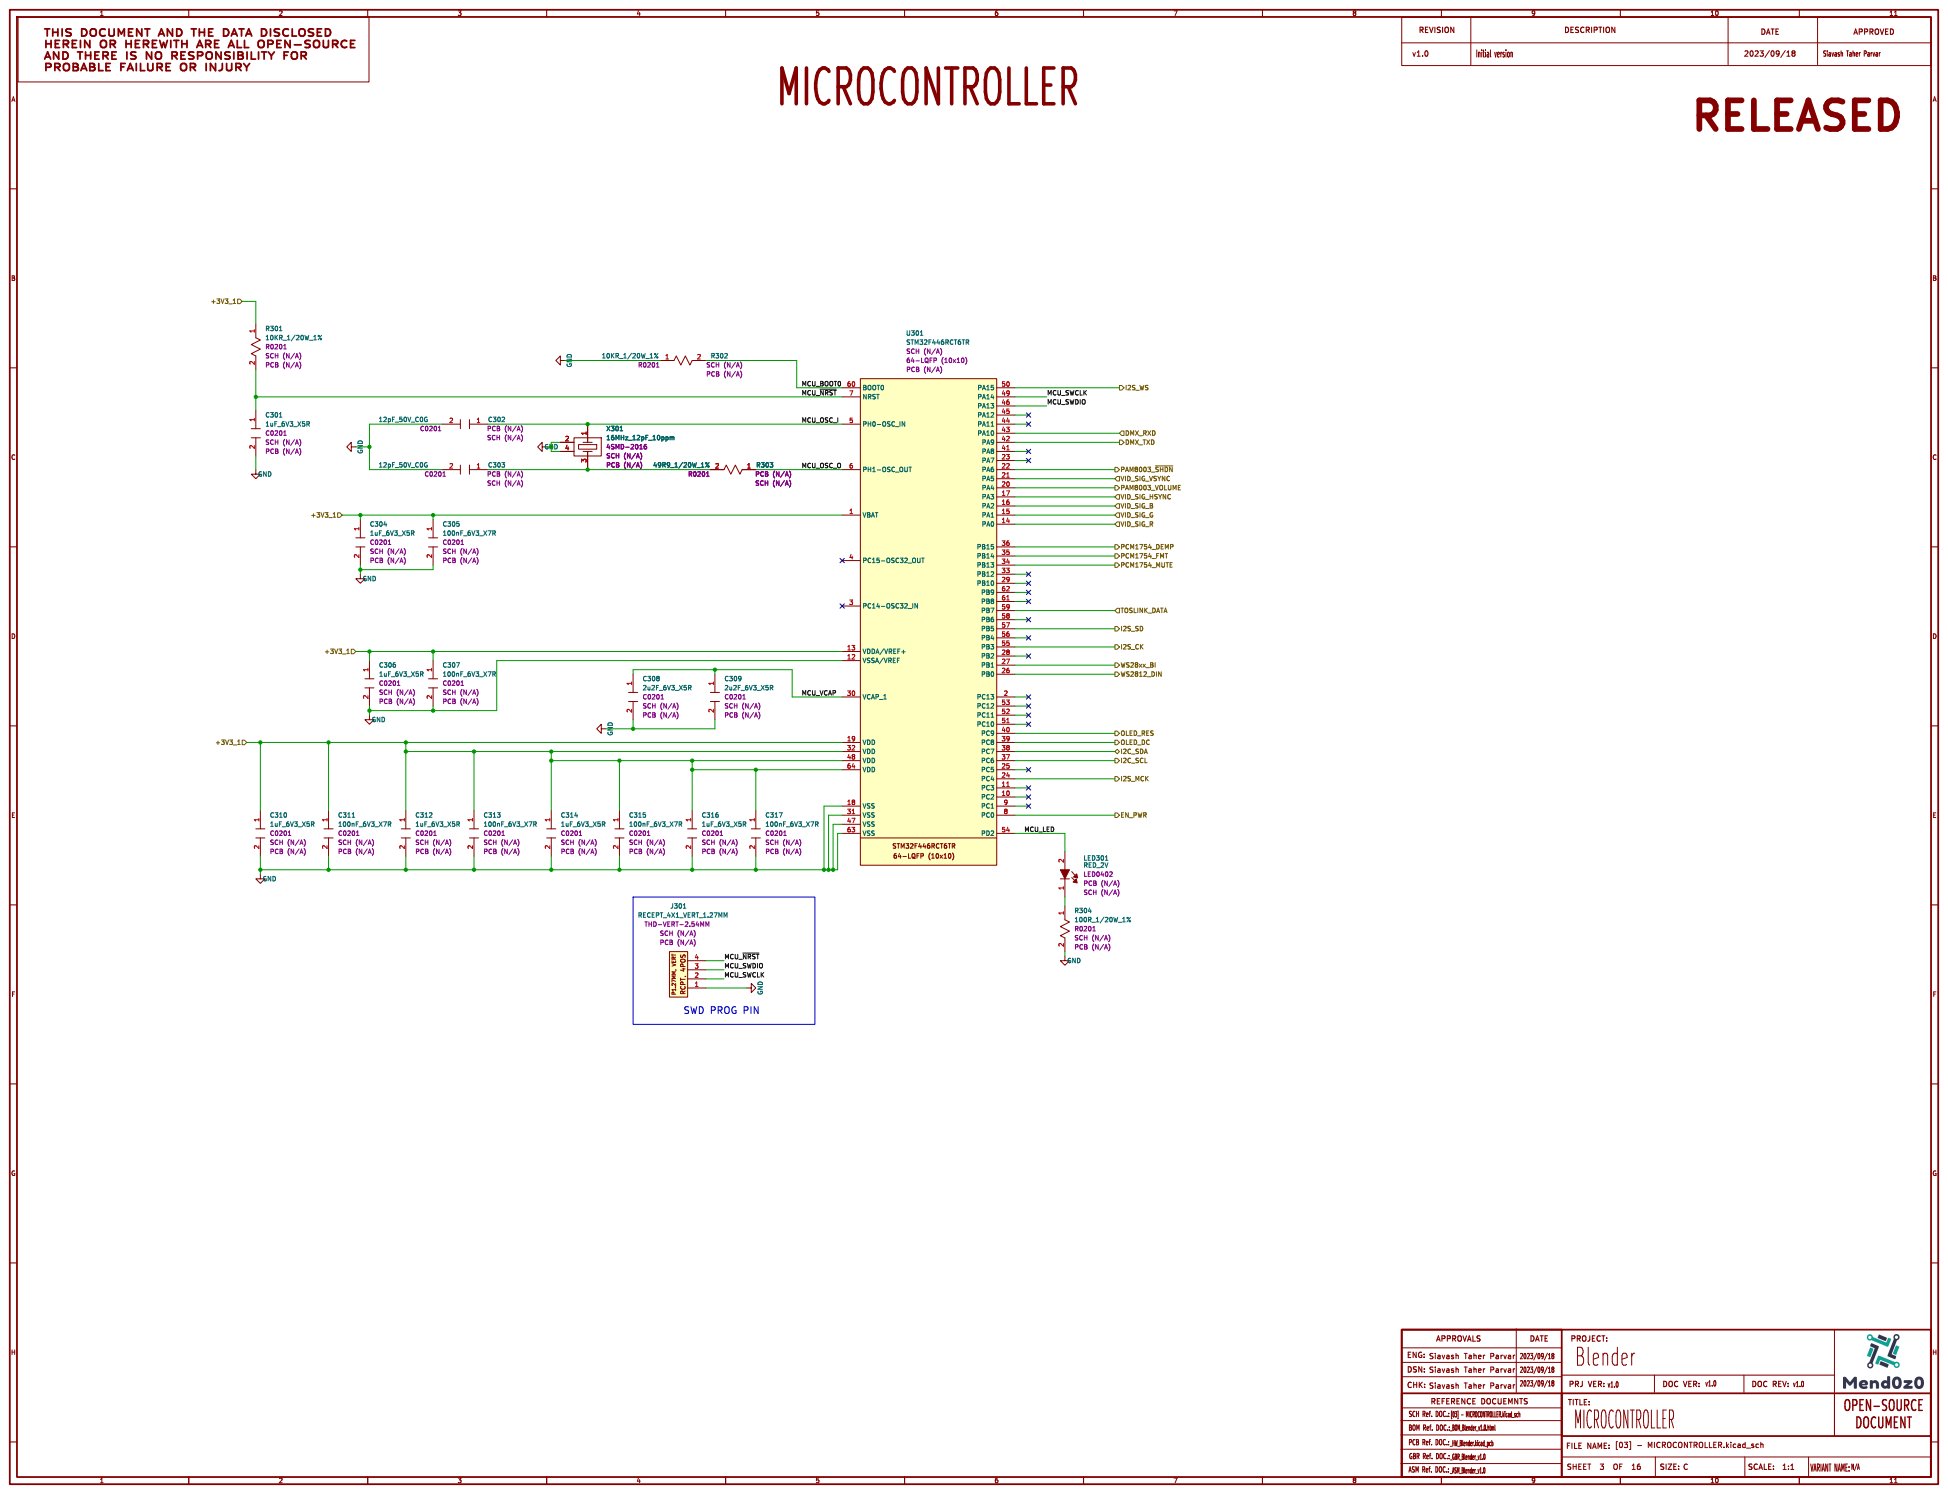
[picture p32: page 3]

MCU_SWDIO MCU_~{NRST} MCU_OSC_O SWD PROG PIN

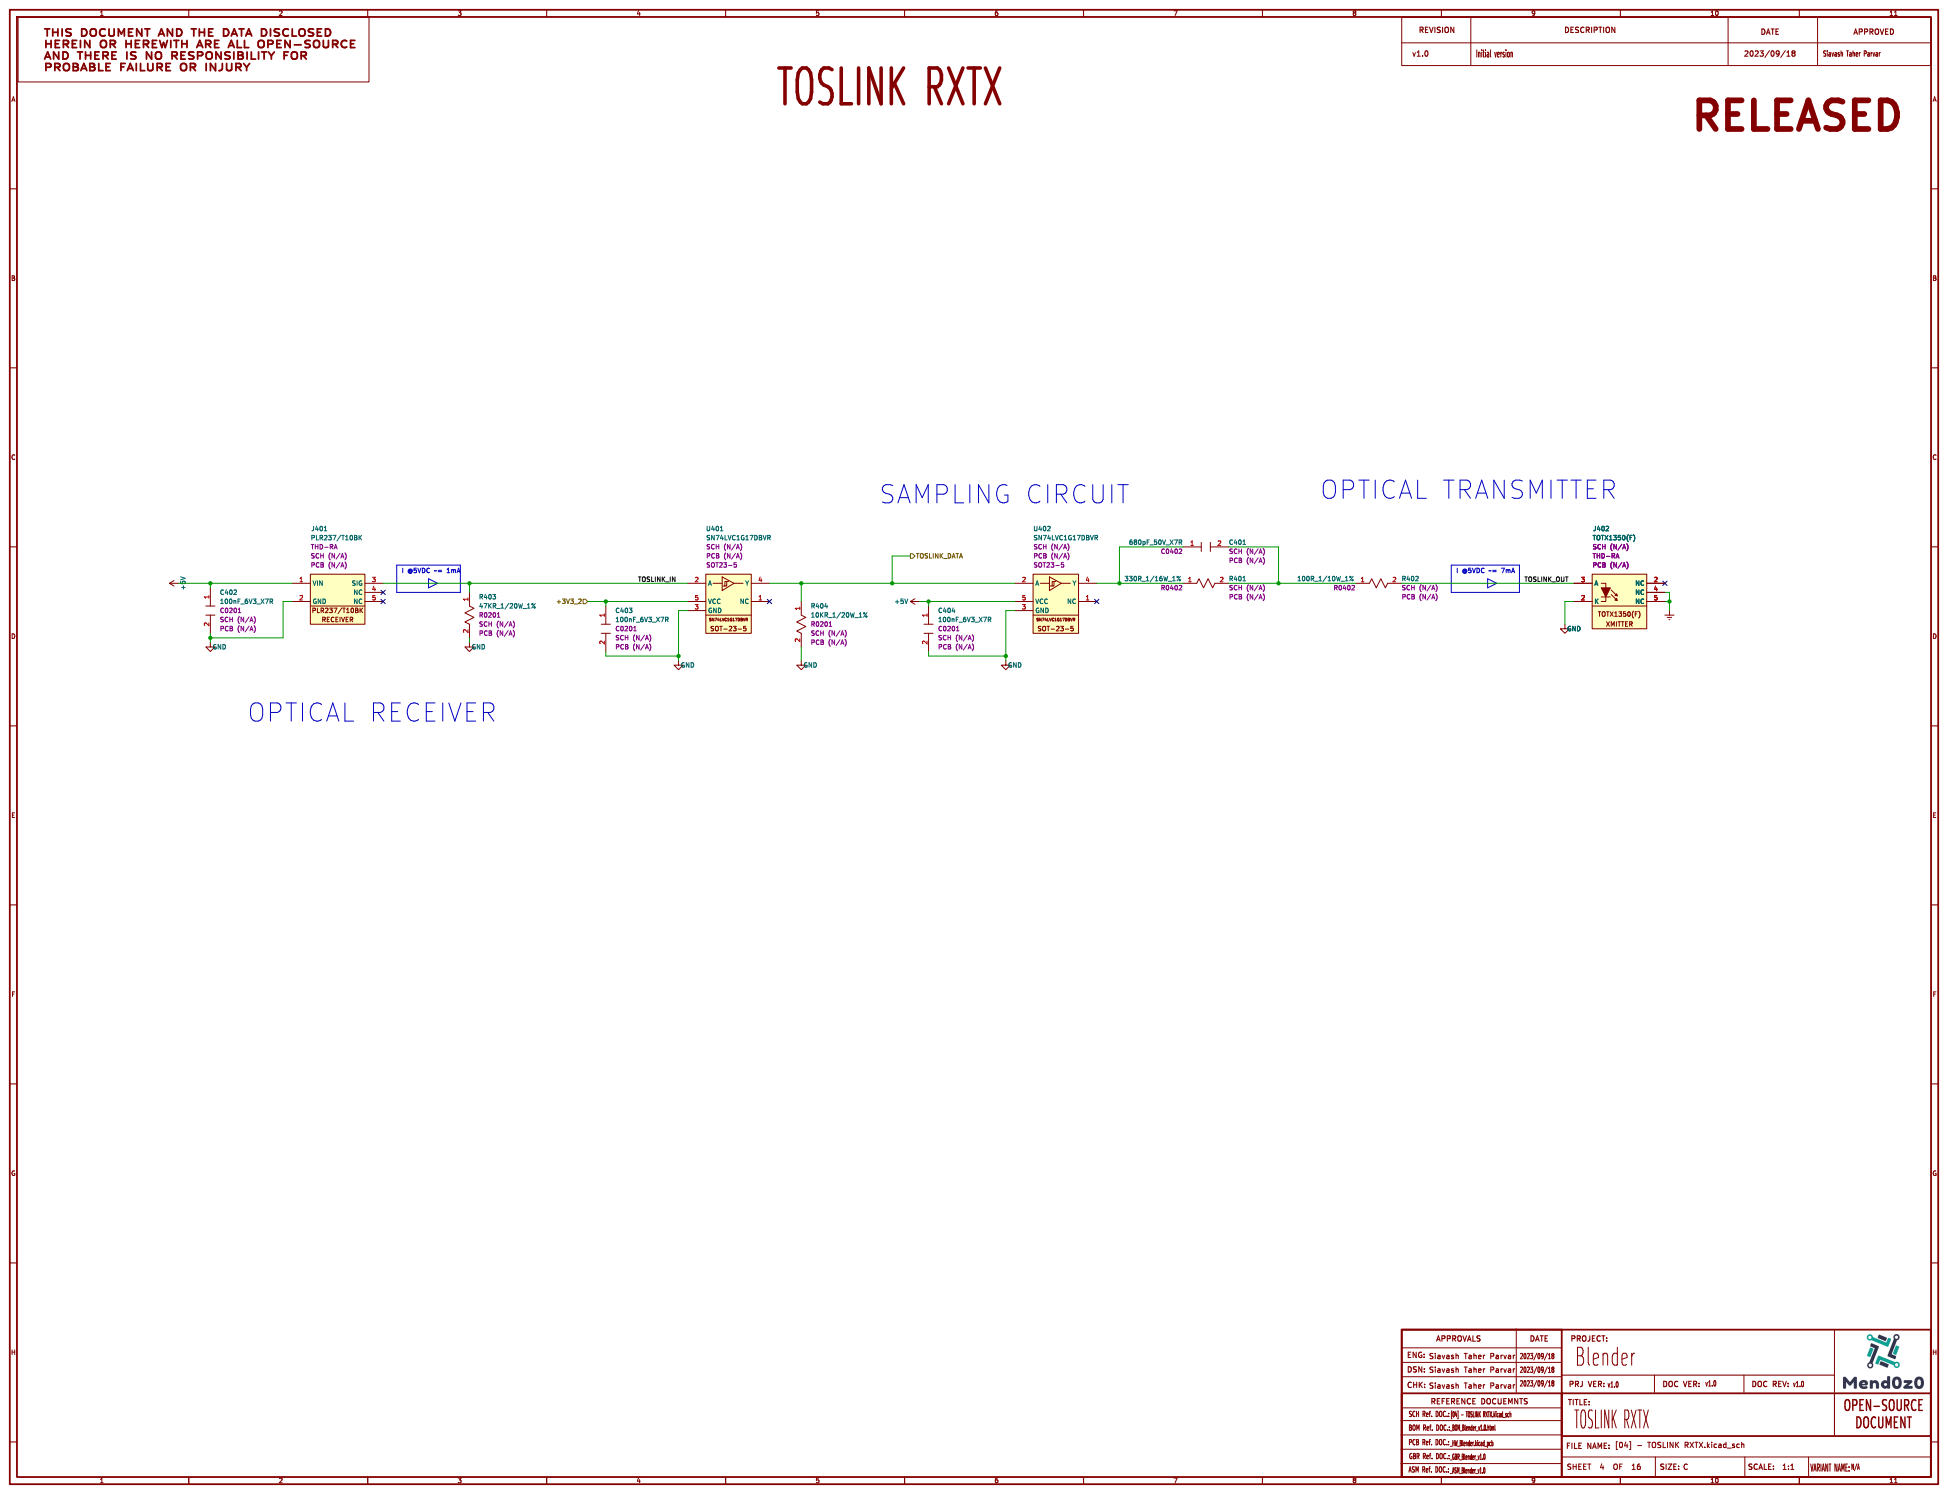
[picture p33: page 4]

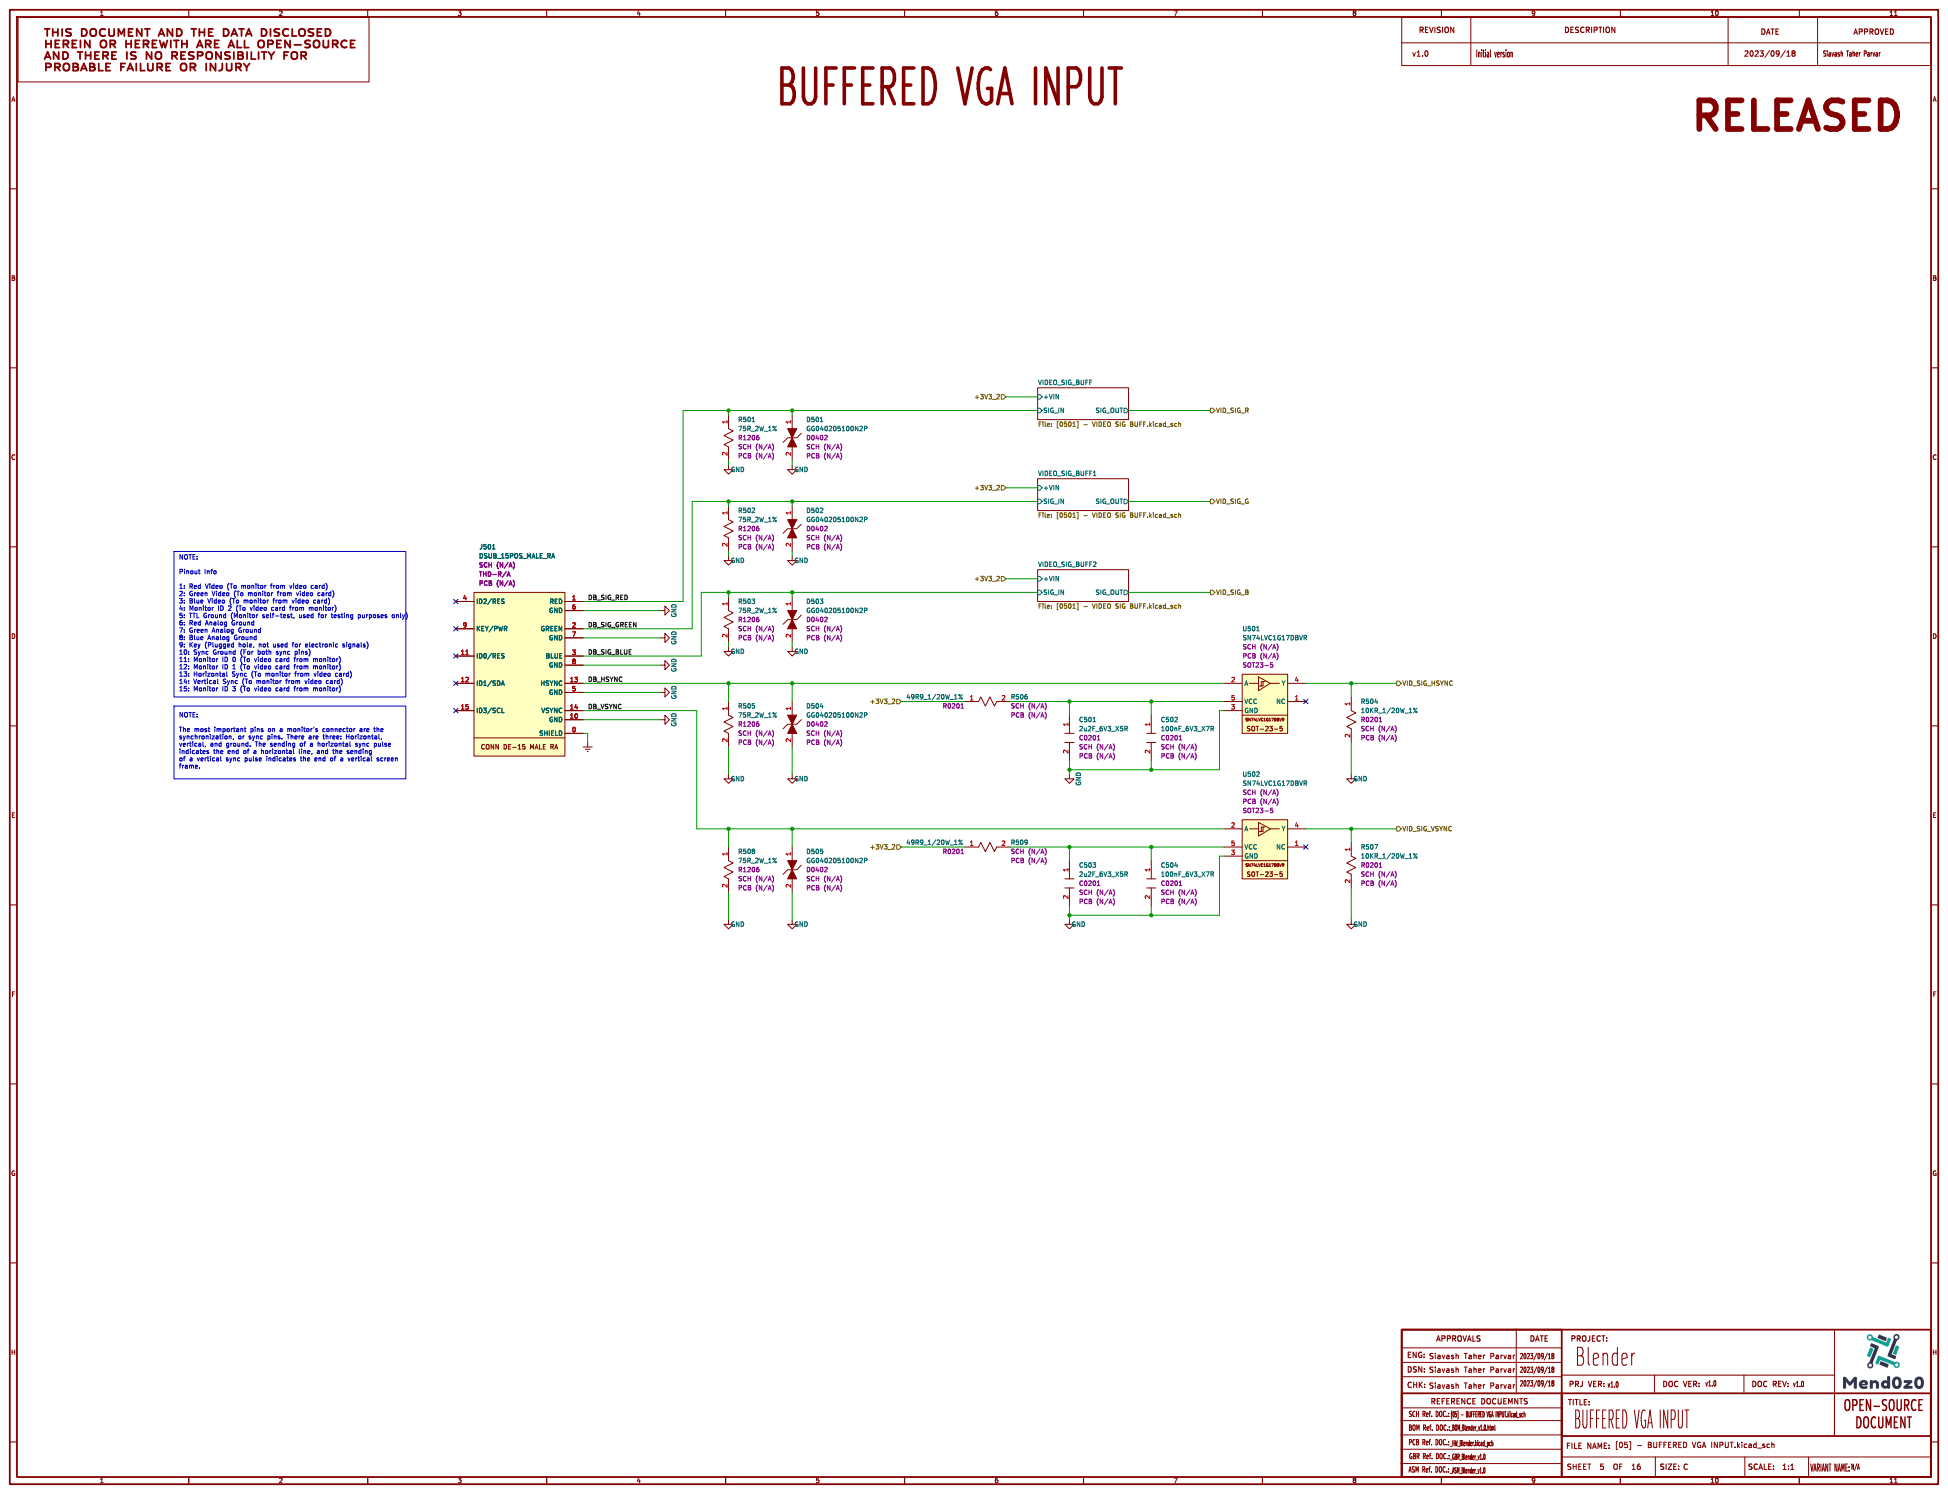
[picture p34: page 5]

frame. NOTE: Pinout Info

SCH (N/A) R0201 PCB (N/A) GND GND

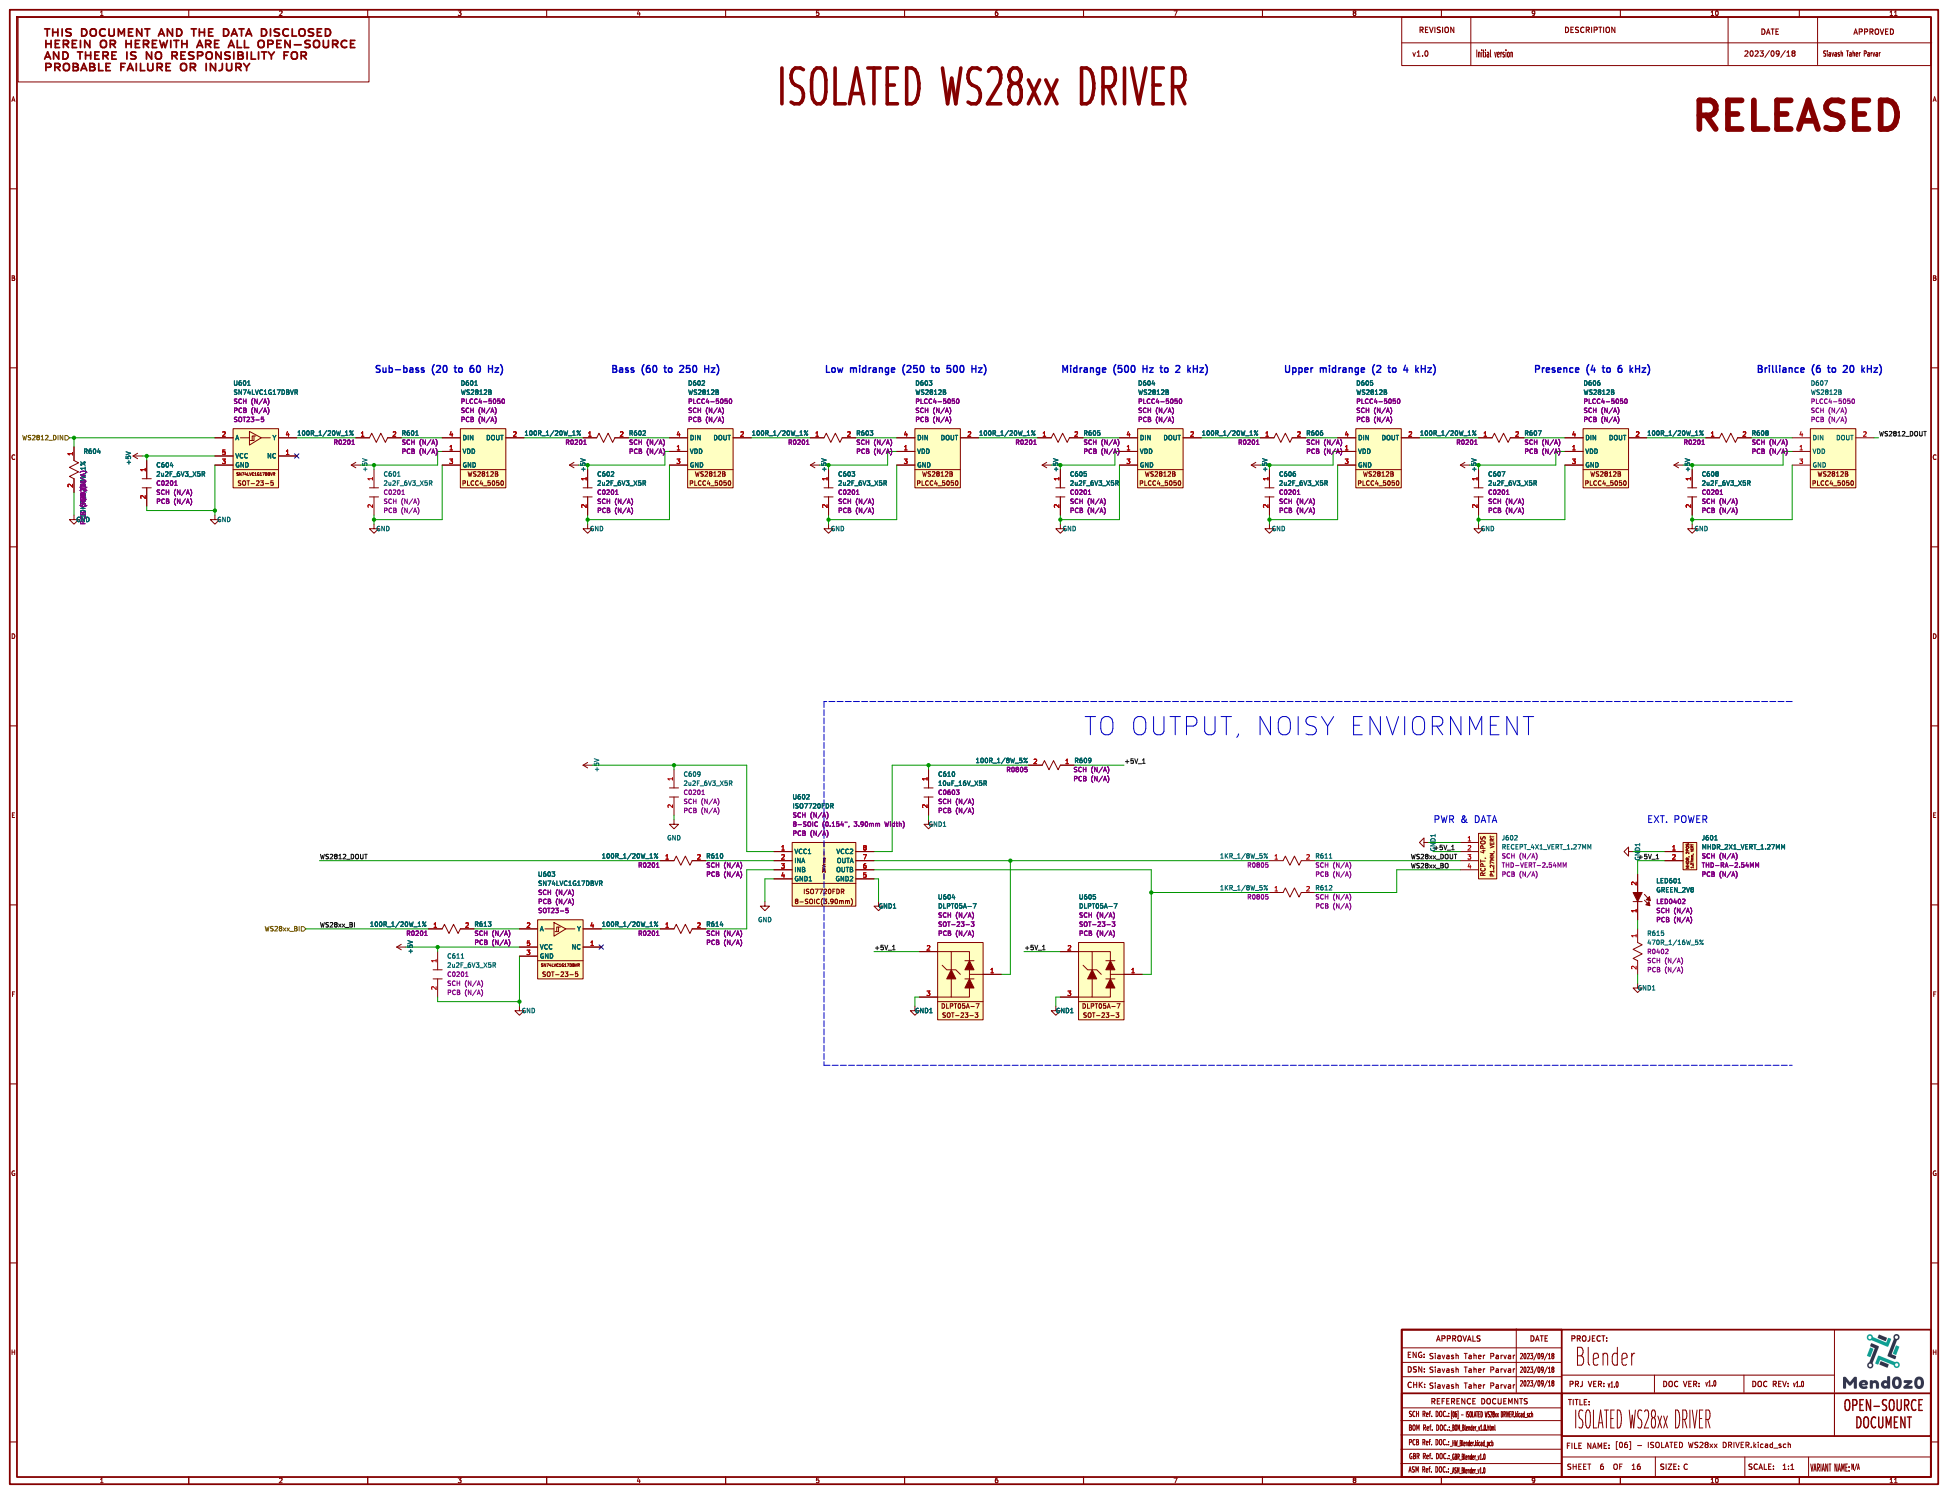
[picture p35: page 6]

TO OUTPUT, NOISY ENVIORNMENT

3 U604 DLPT05A-7 SCH (N/A) SOT-23-3 PCB (N/A) GND

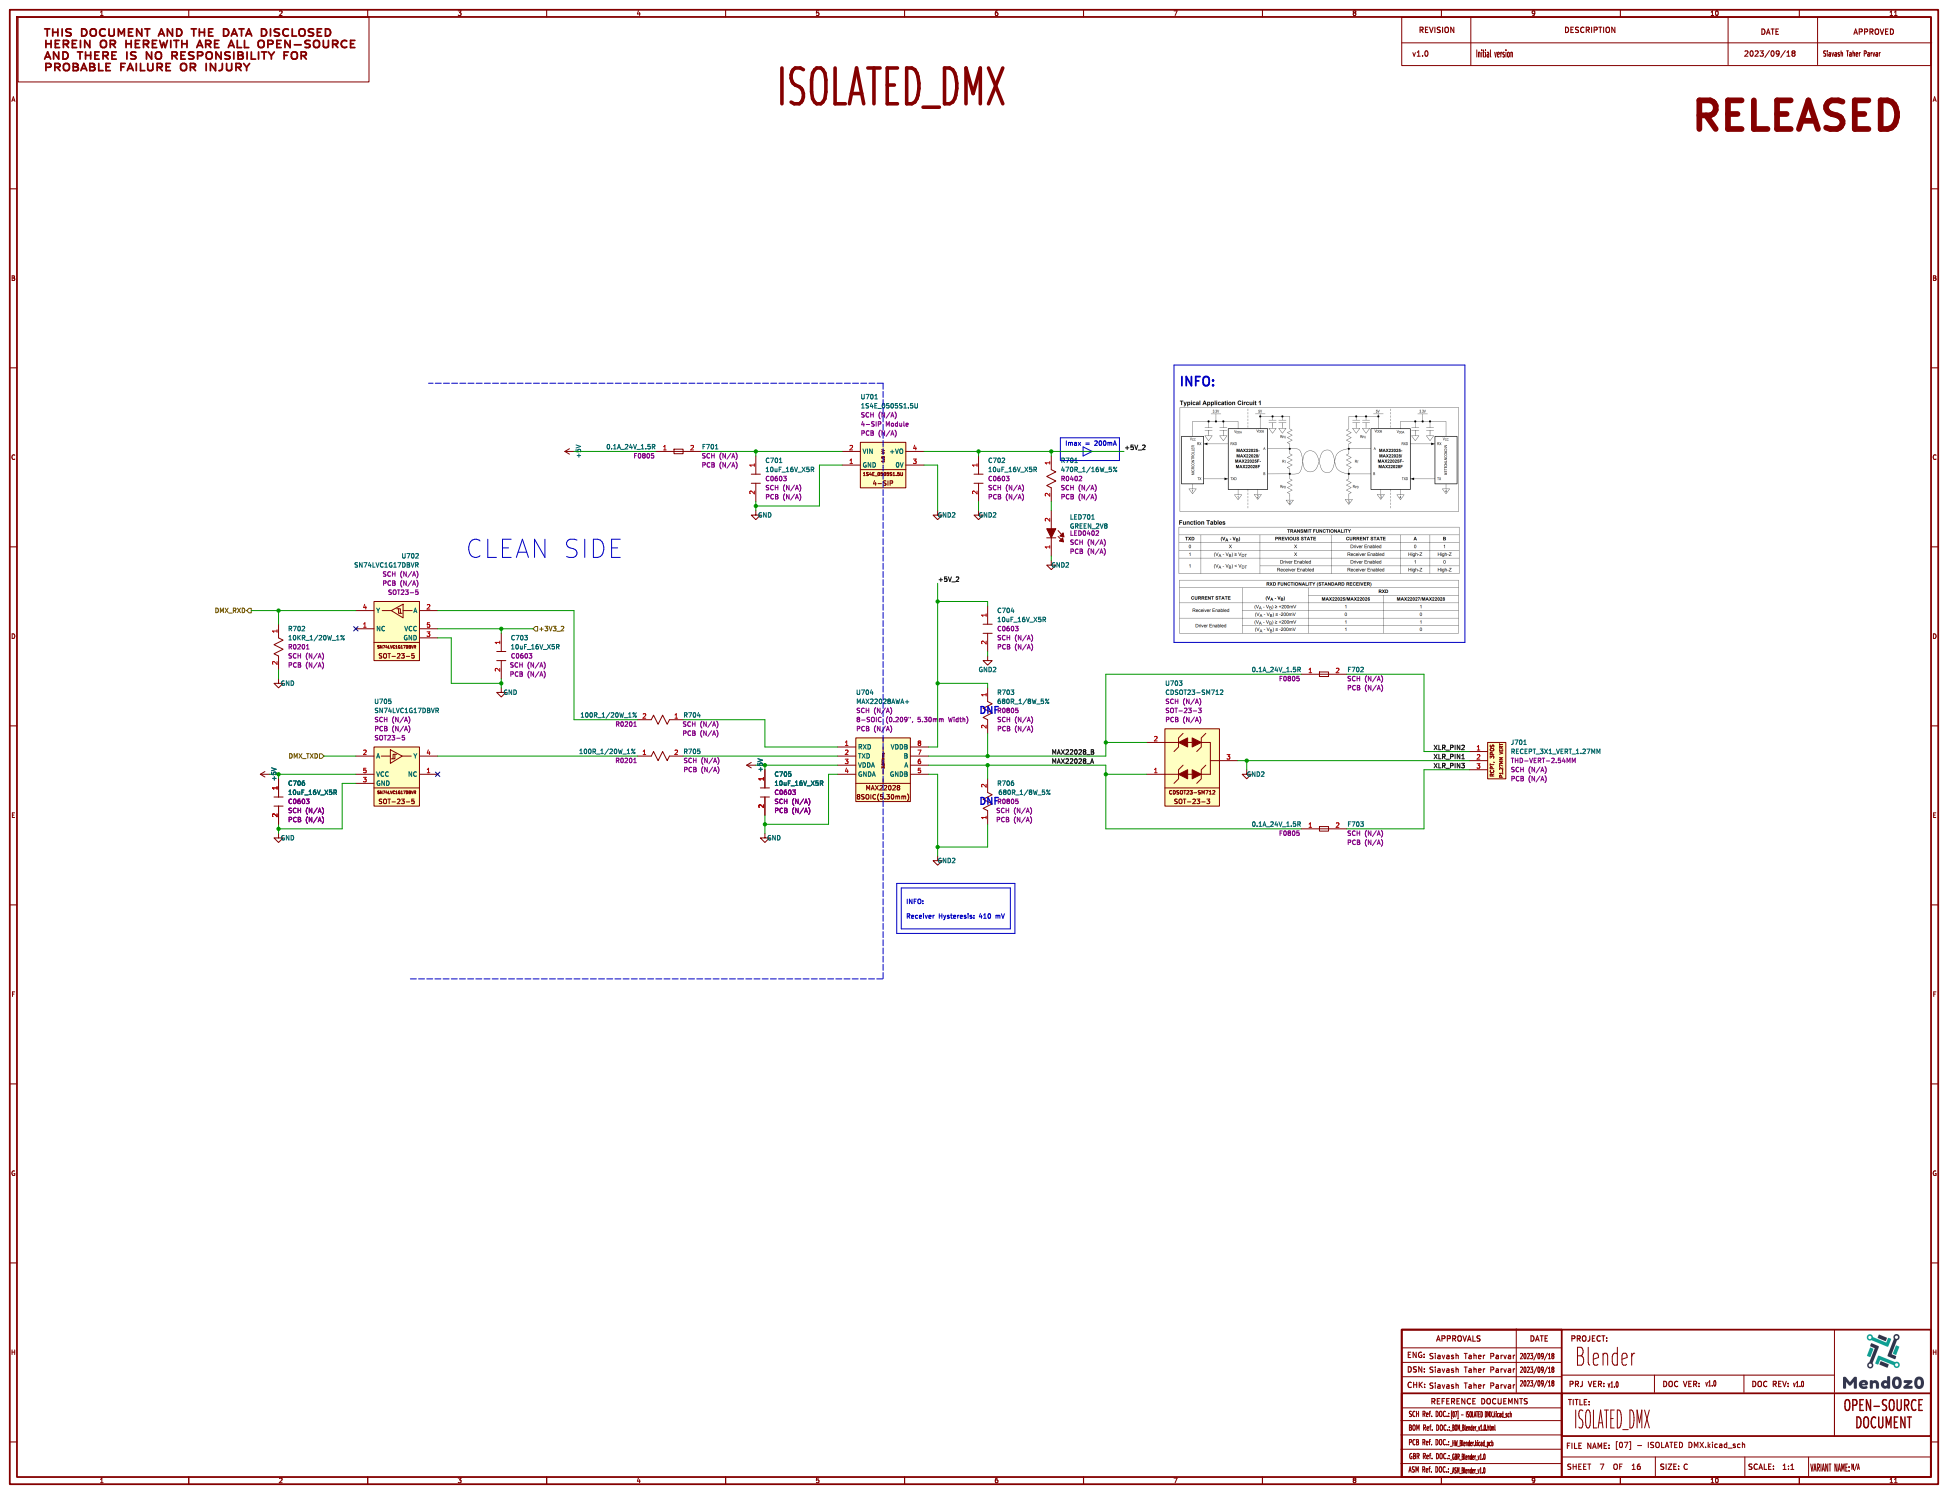
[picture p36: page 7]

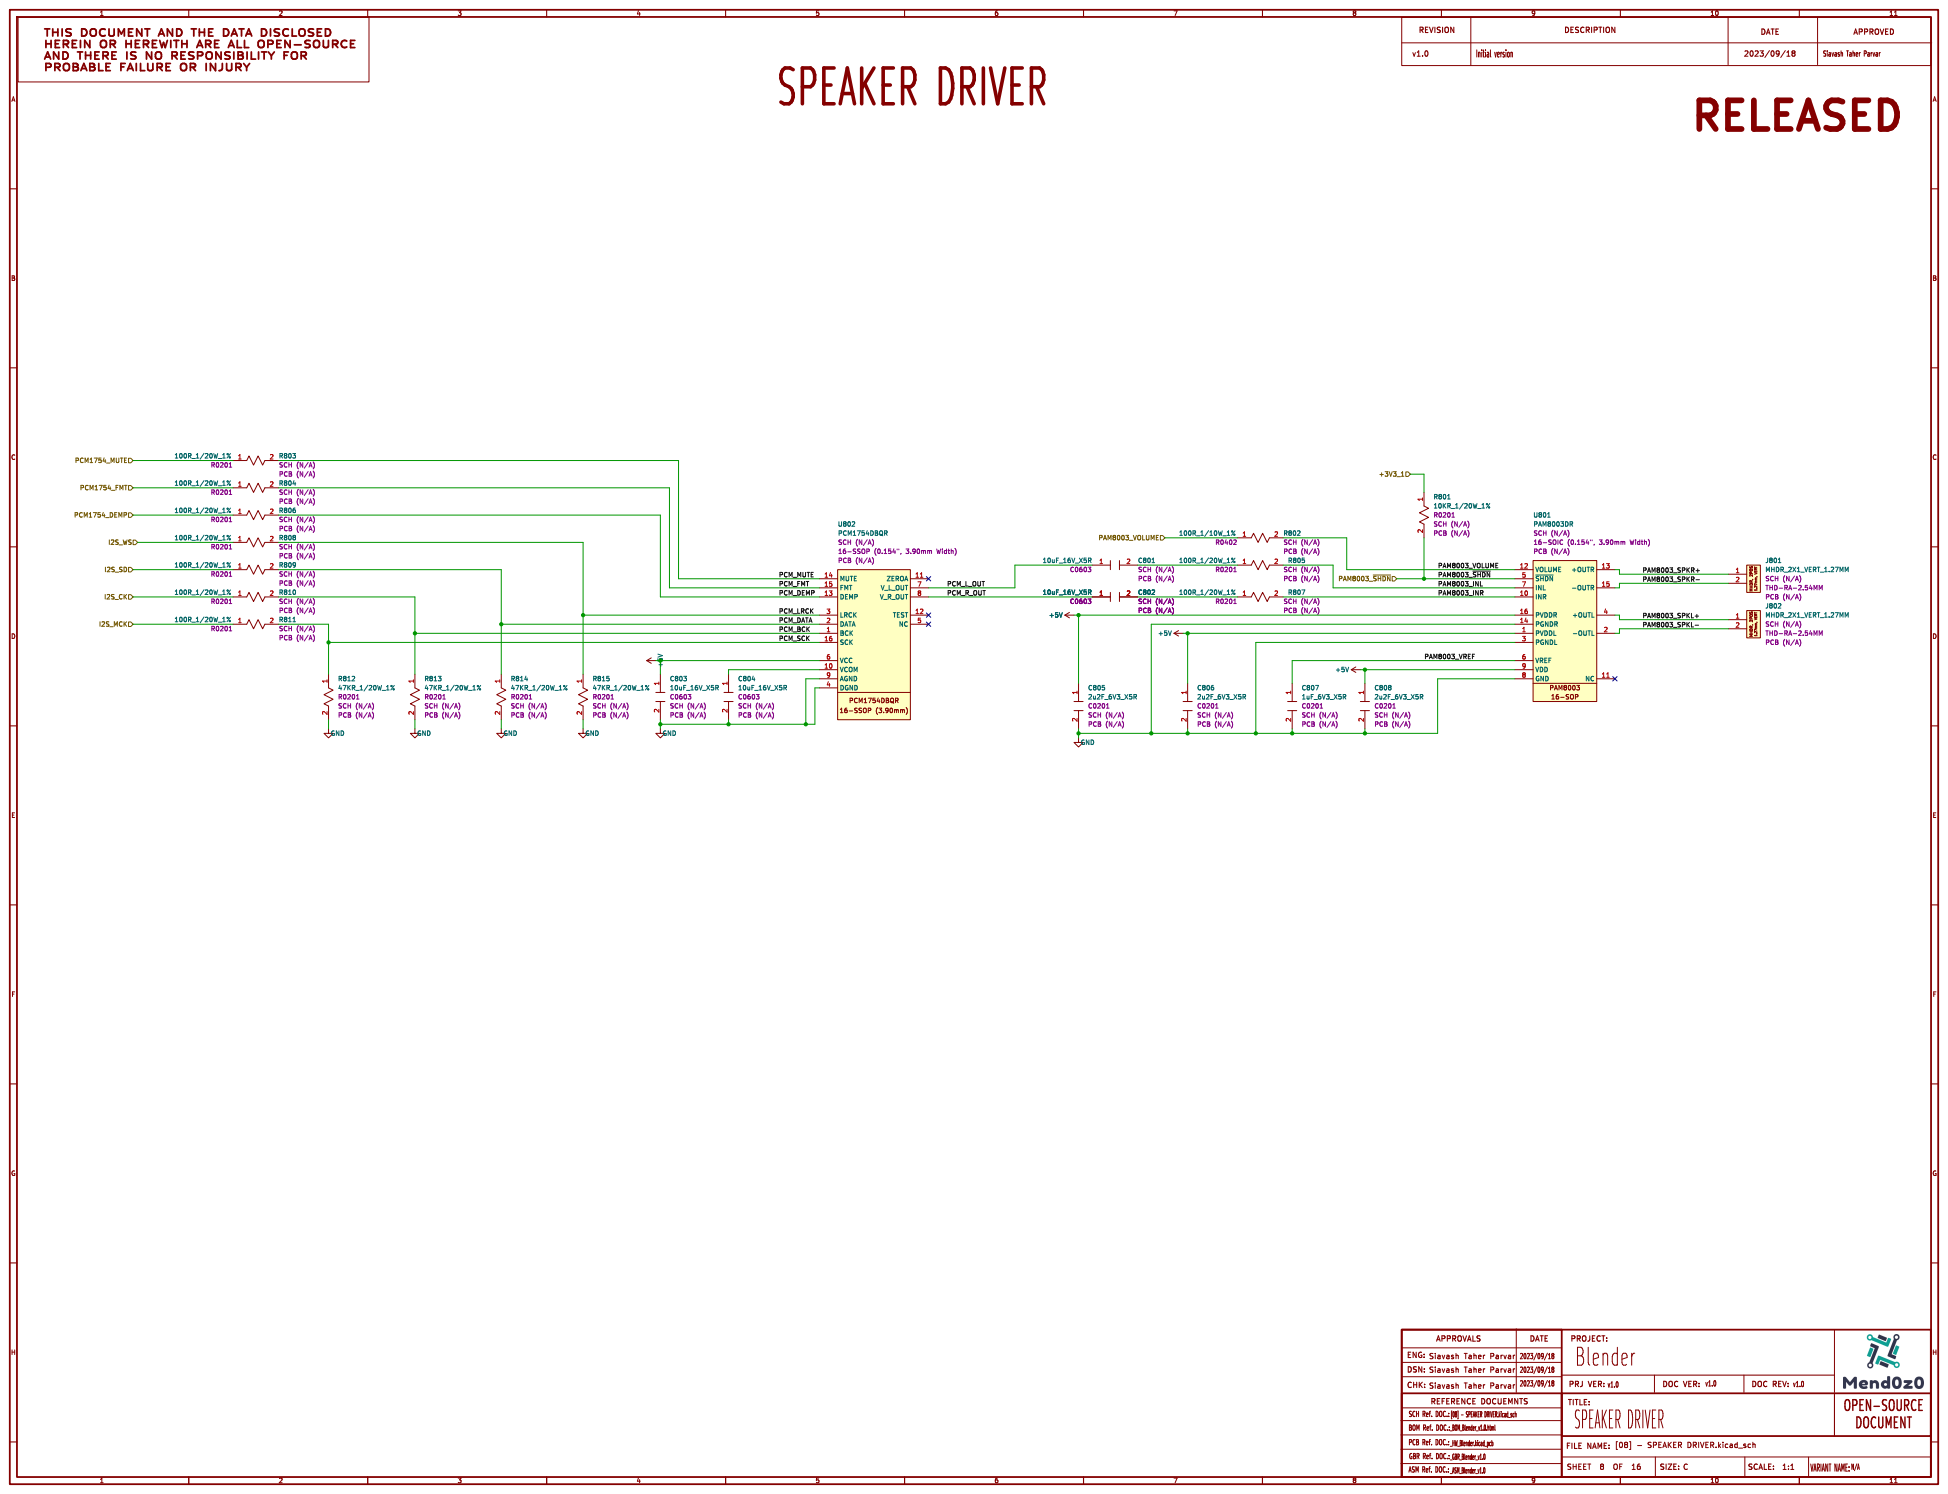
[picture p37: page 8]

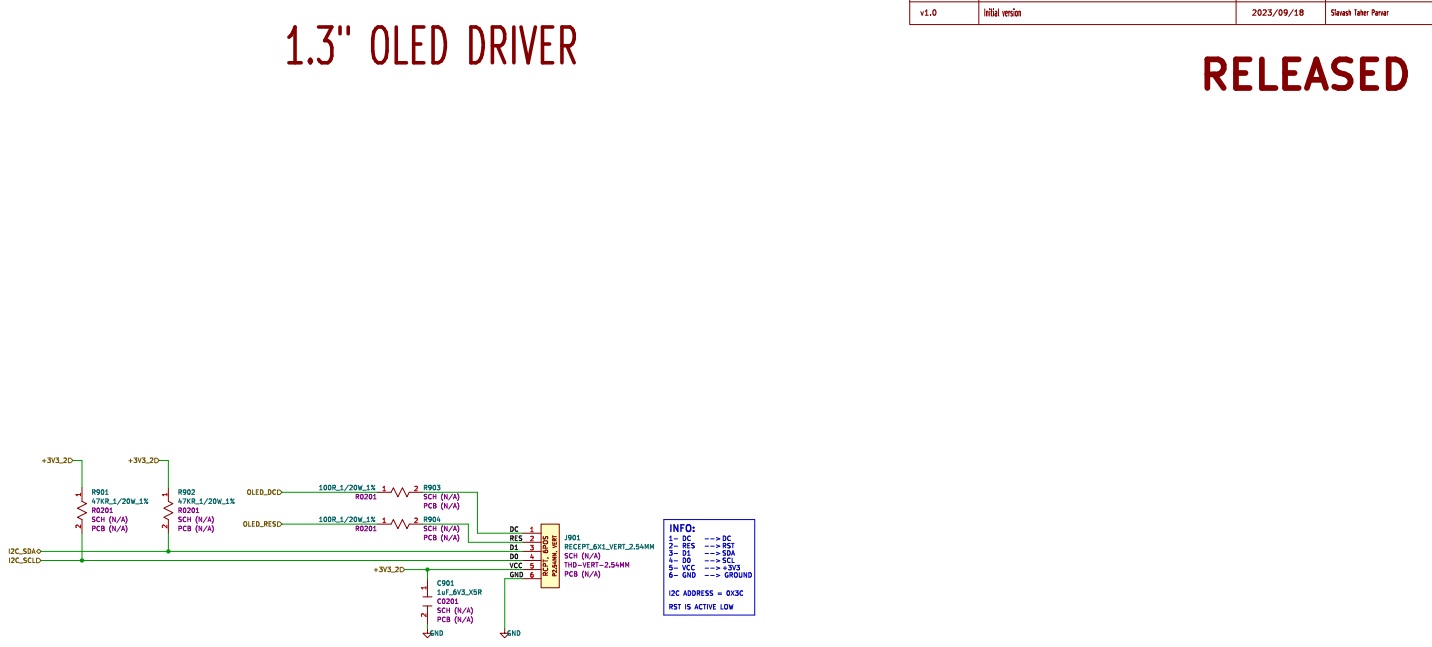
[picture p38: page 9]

I2C ADDRESS = 0X3C
RST IS ACTIVE LOW

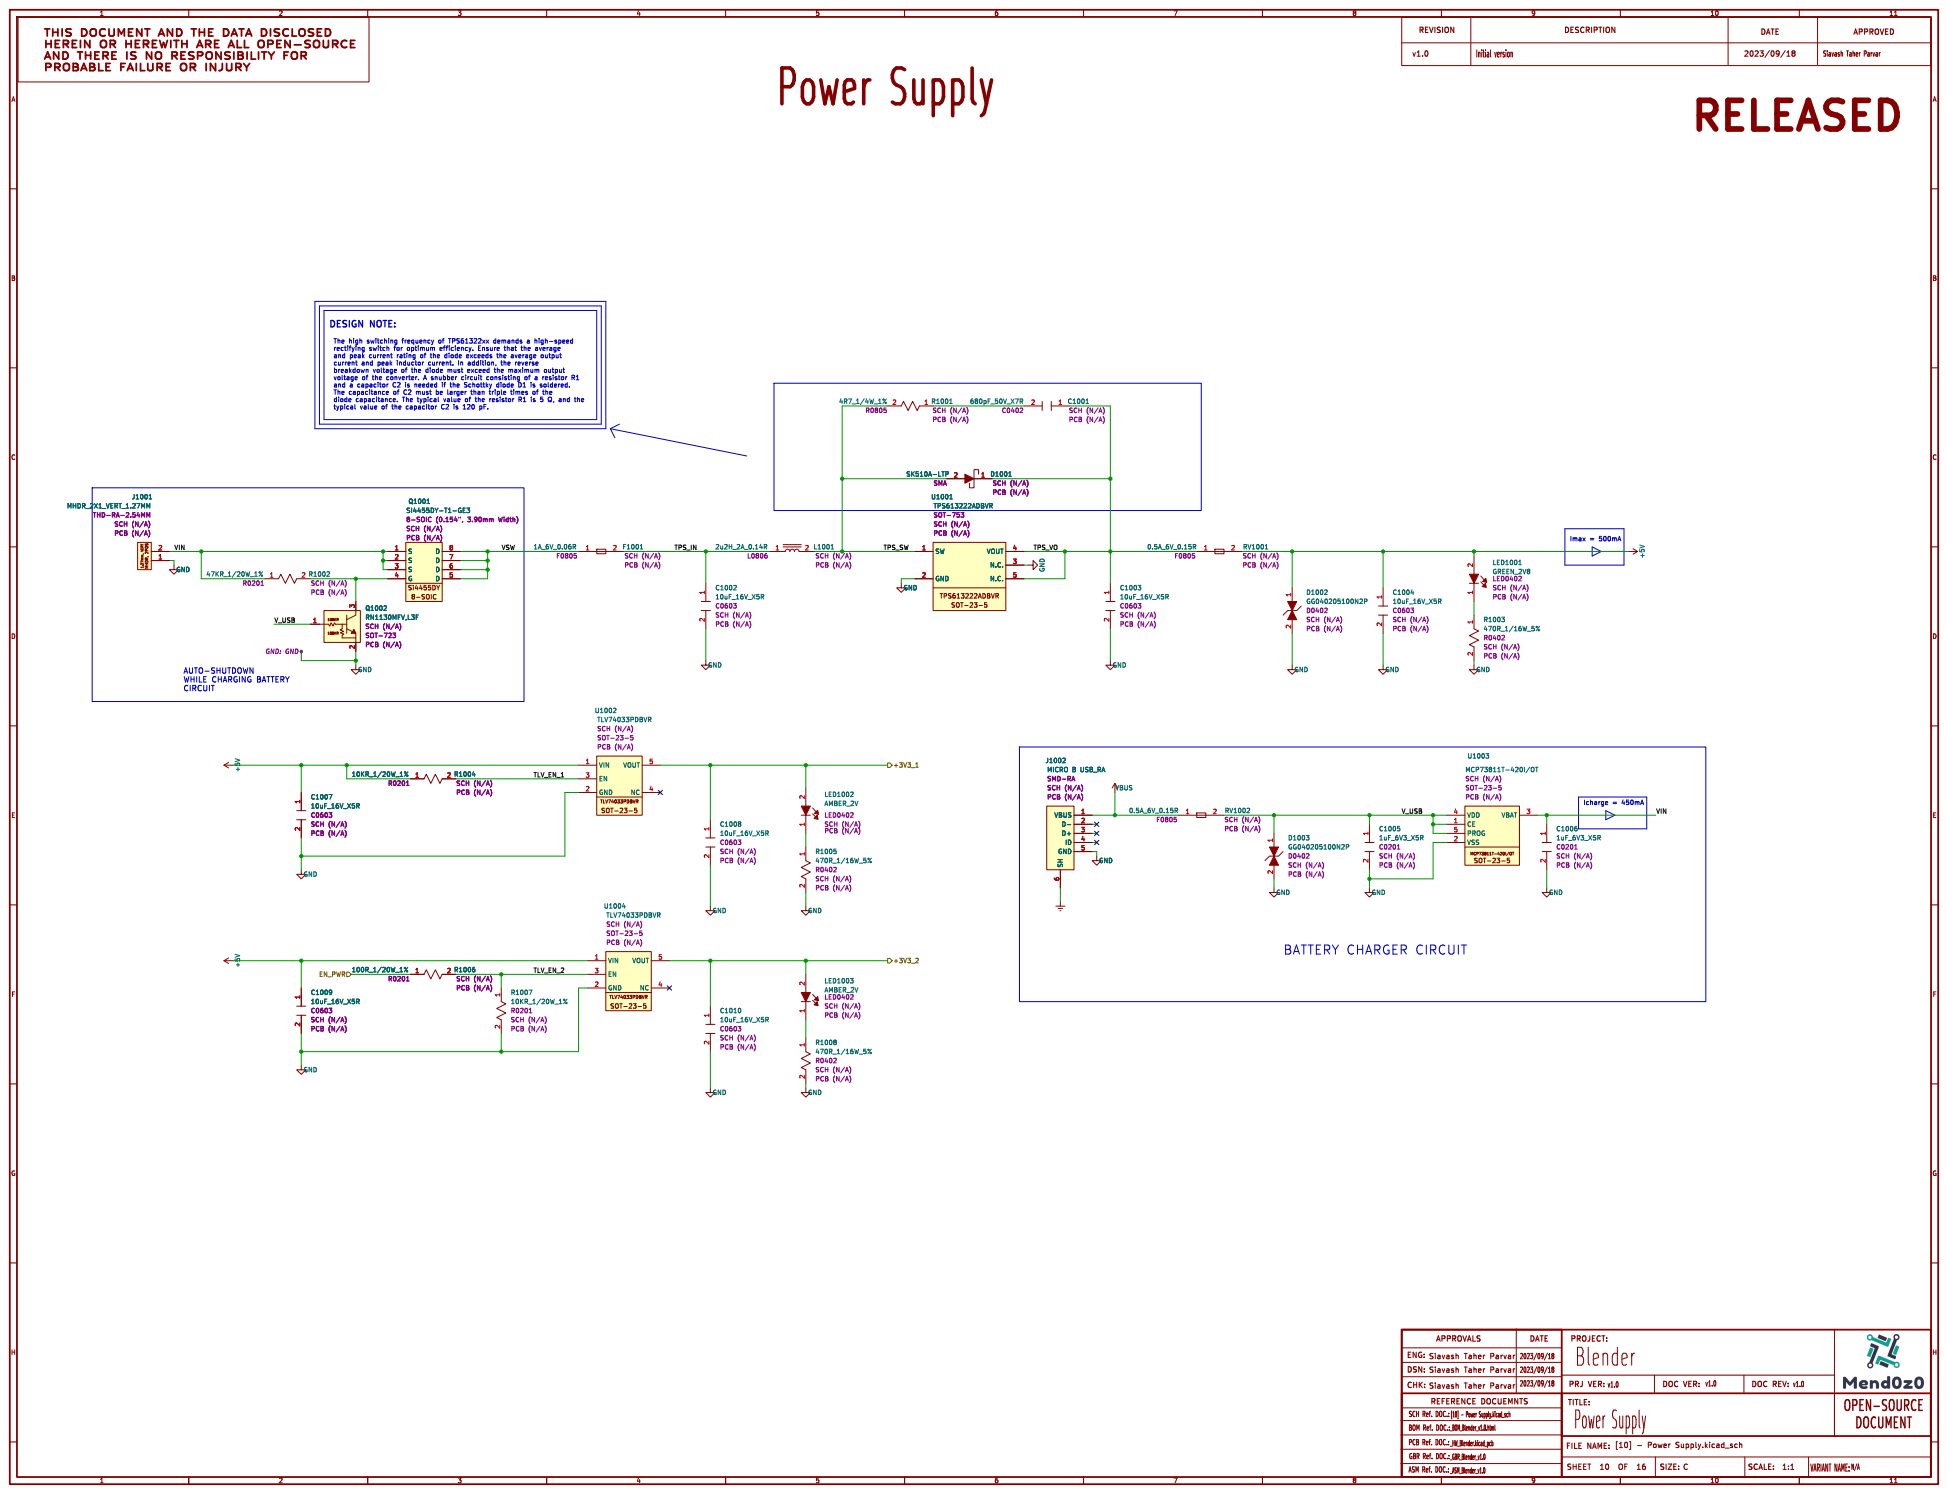
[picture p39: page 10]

Icharge = 450mA AUTO-SHUTDOWN WHILE CHARGING BATTERY CIRCUIT

SCH (N/A) SOT-23-5 PCB (N/A) SOT-23-5

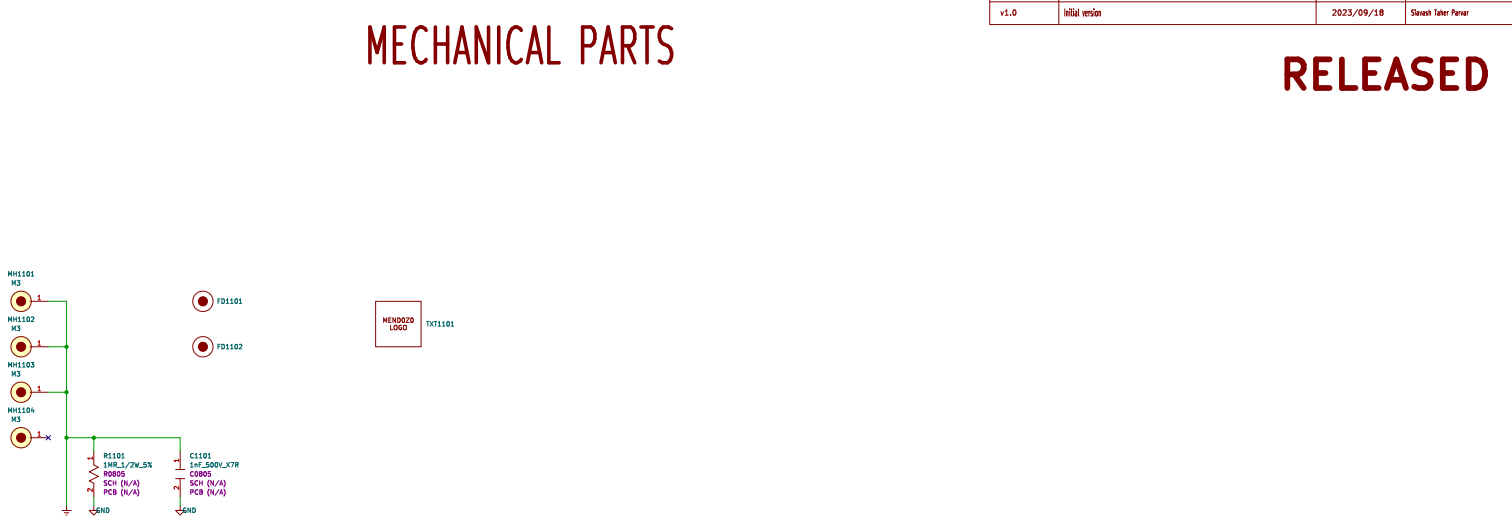
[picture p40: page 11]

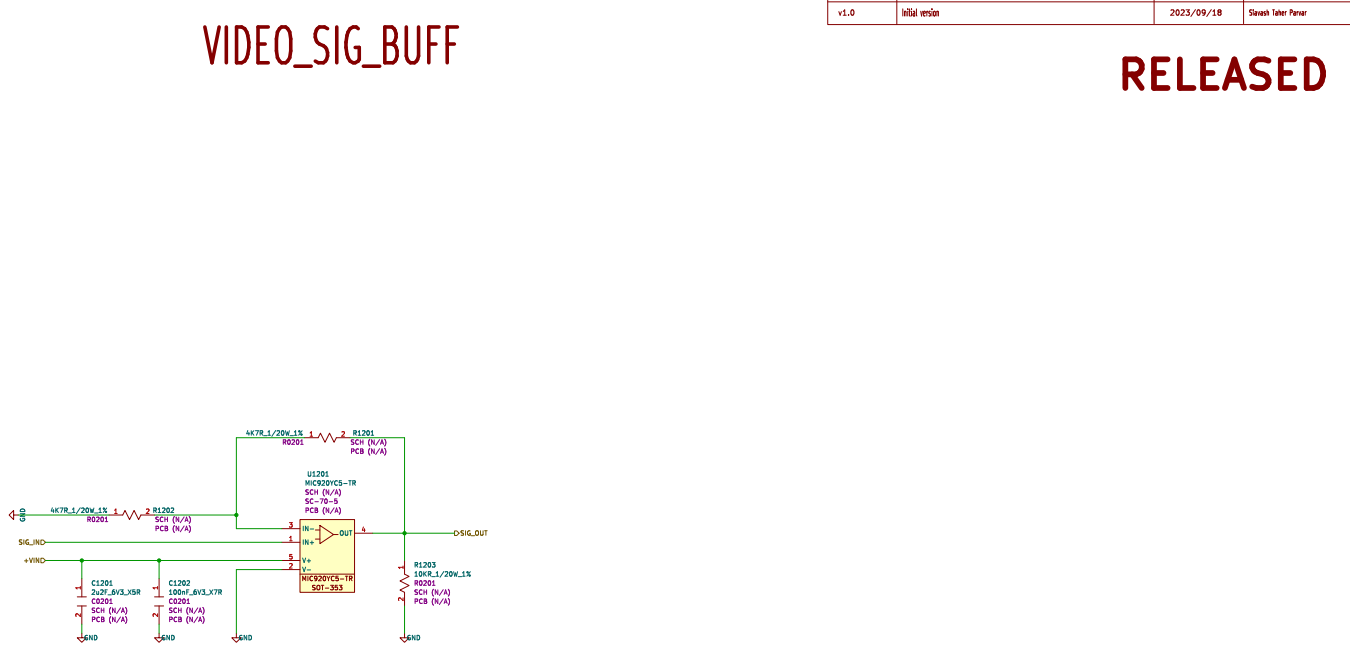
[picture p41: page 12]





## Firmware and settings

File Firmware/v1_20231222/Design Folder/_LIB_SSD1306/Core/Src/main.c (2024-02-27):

#include "main.h"
#include "stdbool.h"

#define	LED_IND_PIN	GPIO_ODR_OD2
#define	LED_IND_PORT	GPIOD->ODR

#define	EXT_LDO_EN_PIN	GPIO_ODR_OD0
#define	EXT_LDO_EN_PORT	GPIOC->ODR

#define FMPI2C_BUFF_SIZE	128

__IO uint8_t fmp12cBuffer[FMPI2C_BUFF_SIZE];
__IO uint32_t fmp12cMaxNumberOfTransfer = FMPI2C_BUFF_SIZE;
__IO bool fmpi2cReloadFlag = false;
__IO bool fmpi2cStopFlag = false;

void FMPI2C1_EV_IRQHandler( void )
{
  if((FMPI2C1->ISR & FMPI2C_ISR_NACKF) == FMPI2C_ISR_NACKF)	// (1)
    {
      FMPI2C1->ICR |= FMPI2C_ICR_NACKCF;			// (2)
    }
  else if((FMPI2C1->ISR & FMPI2C_ISR_TXIS) == FMPI2C_ISR_TXIS)	// (4)
    {
      if((FMPI2C1->CR1 & FMPI2C_CR1_TXDMAEN) == 0)	//if dma is already started that means we are in the middle of transfer
	{
	      FMPI2C1->CR1 |= FMPI2C_CR1_TXDMAEN;			// DMA mode enabled for transmission
	      FMPI2C1->CR1 &= ~FMPI2C_CR1_TXIE;
	}
      else
	{
	  if(fmp12cMaxNumberOfTransfer == 0)
	    {
	      FMPI2C1->CR2 |= FMPI2C_CR2_STOP;	//this part is for the left over data to be sent.
	    }
	  else
	    {
	      fmp12cMaxNumberOfTransfer--;
	    }
	}
    }
  else if((FMPI2C1->ISR & FMPI2C_ISR_TCR) == FMPI2C_ISR_TCR)
    {
      fmpi2cReloadFlag = true;
    }
  else if((FMPI2C1->ISR & FMPI2C_ISR_STOPF) == FMPI2C_ISR_STOPF)
    {
      FMPI2C1->ICR |= FMPI2C_ICR_STOPCF;
      fmpi2cStopFlag = true;
    }
}

static void _init_RCC( void );
static void _init_GPIO( void );
int32_t FMPI2C1DataTx( uint8_t slaveAddr, uint8_t *data, uint32_t buffSize);


int main(void)
{
  _init_RCC();
  _init_GPIO();

  SET_BIT( EXT_LDO_EN_PORT, EXT_LDO_EN_PIN);	//Enable the LDO power to turn the modules on

  while (1)
    {
      if(READ_BIT(LED_IND_PORT, LED_IND_PIN))	// (4)
	{
	  CLEAR_BIT(LED_IND_PORT, LED_IND_PIN);	// (5)
    	}
      else
  	{
    	  SET_BIT( LED_IND_PORT, LED_IND_PIN);	// (6)
    	}
      for(uint32_t i = 0; i < 1800000; ++i);
    }
}

static void _init_RCC( void )
{

  ////--------------Enabling the HSE
  RCC->CR |= RCC_CR_HSEON;				// (1)
  while((RCC->CR & RCC_CR_HSERDY) == 0)			// (2)
    {
      //maybe add a time out later
    }

  ////--------------Configuration for PLLs
  RCC->PLLCFGR |= RCC_PLLCFGR_PLLSRC;			// (3)

  // Fosc_in = 16 MHz
    // PLLM = 10
    // PLLN = 200
    // PLLP = 2
    // Fpll = (16 * (240 / 6)) / 4 = 160 MHz

    RCC->PLLCFGR |= 0x0A | (0xC8 << 6);

  RCC->PLLCFGR |= RCC_PLLCFGR_PLLR_1;			// (5)


  RCC->CR |= RCC_CR_PLLON;				// (6)

  while((RCC->CR & RCC_CR_PLLRDY) == 0)			// (7)
    {
      //maybe add a time out later
    }

  RCC->CFGR |= RCC_CFGR_HPRE_3;				// 80MHz
  RCC->CFGR |= RCC_CFGR_PPRE1_0 | RCC_CFGR_PPRE1_2; 	// 40MHz
  RCC->CFGR |= RCC_CFGR_PPRE2_2;			// 80MHz

  RCC->CFGR |= RCC_CFGR_SW_1;				// (8)
  while((RCC->CFGR & RCC_CFGR_SWS_1) != RCC_CFGR_SWS_1)	// (9)
    {
      //maybe add a time out later
    }

  RCC->AHB1ENR |= (	RCC_AHB1ENR_GPIOAEN |		// (13)
			RCC_AHB1ENR_GPIOBEN |		// (14)
			RCC_AHB1ENR_GPIOCEN |		// (15)
			RCC_AHB1ENR_GPIODEN		// (16)
  );

  RCC->AHB1ENR |= (	RCC_AHB1ENR_DMA1EN	| 	// (17)
			RCC_AHB1ENR_DMA2EN		// (18)
  );

  RCC->APB2ENR |= RCC_APB2ENR_USART1EN;			// (27)
}

static void _init_GPIO( void )
{
  /*		MODER REGs		*/
  GPIOA->MODER |= (	GPIO_MODER_MODER4_0  | GPIO_MODER_MODER4_1 |				// (1)
			GPIO_MODER_MODER6_0  |							// (2)
			GPIO_MODER_MODER0_0  | GPIO_MODER_MODER0_1 |  				// (3)
			GPIO_MODER_MODER1_0  | GPIO_MODER_MODER1_1 |  				// (4)
			GPIO_MODER_MODER2_0  | GPIO_MODER_MODER2_1 |  				// (5)
			GPIO_MODER_MODER9_1  |							// (6)
			GPIO_MODER_MODER10_1 |							// (7)
			GPIO_MODER_MODER3_1  |							// (8)
			GPIO_MODER_MODER5_1  |							// (9)
			GPIO_MODER_MODER15_1							// (10)
  );

  GPIOB->MODER |= (	GPIO_MODER_MODER13_0 |							// (11)
			GPIO_MODER_MODER14_0 |							// (12)
			GPIO_MODER_MODER15_0 |							// (13)
			GPIO_MODER_MODER3_1  |							// (14)
			GPIO_MODER_MODER5_1  |							// (15)
			GPIO_MODER_MODER0_1  |							// (16)
			GPIO_MODER_MODER1_1  |							// (17)
			GPIO_MODER_MODER7_1	 						// (18)
  );

  GPIOC->MODER |= (	GPIO_MODER_MODER0_0  |							// (19)
			GPIO_MODER_MODER8_0  |							// (20)
			GPIO_MODER_MODER9_0  |							// (21)
			GPIO_MODER_MODER4_1  |							// (22)
			GPIO_MODER_MODER6_1	 |						// (23)
			GPIO_MODER_MODER7_1							// (24)
  );

  GPIOD->MODER |= GPIO_MODER_MODER2_0;								// (25)

  /*		OSPEEDR	REGs	*/
  GPIOA->OSPEEDR |= (	GPIO_OSPEEDR_OSPEED3_0	|						// (26)
			GPIO_OSPEEDR_OSPEED5_0	|						// (27)
			GPIO_OSPEEDR_OSPEED15_0	|
			GPIO_OSPEEDR_OSPEED9_0  | GPIO_OSPEEDR_OSPEED9_1
  );

  GPIOB->OSPEEDR |= (	GPIO_OSPEEDR_OSPEED3_0	|						// (29)
			GPIO_OSPEEDR_OSPEED5_0	|						// (30)
			GPIO_OSPEEDR_OSPEED0_0	| GPIO_OSPEEDR_OSPEED0_1 |			// (31)
			GPIO_OSPEEDR_OSPEED1_0	|						// (32)
			GPIO_OSPEEDR_OSPEED7_0							// (33)
  );

  GPIOA->PUPDR |= GPIO_PUPDR_PUPDR9_1;	// internal pull down resistor


  /*		AFRL REGs		*/
  GPIOA->AFR[0] |= (	GPIO_AFRL_AFSEL3_0   |							// (34)
			GPIO_AFRL_AFSEL5_0	 						// (35)
  );

  GPIOA->AFR[1] |= (	(GPIO_AFRH_AFSEL9_0  | GPIO_AFRH_AFSEL9_1 | GPIO_AFRH_AFSEL9_2) |	// (36)
			(GPIO_AFRH_AFSEL10_0 | GPIO_AFRH_AFSEL10_1 | GPIO_AFRH_AFSEL10_2) |	// (37)
			(GPIO_AFRH_AFSEL15_0 | GPIO_AFRH_AFSEL15_2)				// (38)
  );

  GPIOB->AFR[0] |= (	(GPIO_AFRL_AFSEL3_0 | GPIO_AFRL_AFSEL3_2) |				// (39)
			(GPIO_AFRL_AFSEL5_0 | GPIO_AFRL_AFSEL5_2) |				// (40)
			GPIO_AFRL_AFSEL0_1 	|						// (41)
			GPIO_AFRL_AFSEL1_1 	|						// (42)
			GPIO_AFRL_AFSEL7_3							// (43)
  );

  GPIOC->AFR[0] |= (	GPIO_AFRL_AFSEL6_2	|						// (44)
			GPIO_AFRL_AFSEL7_2							// (45)
  );

  /*	RESET VALUE	*/
  GPIOA->ODR = 0;																				// (46)
  GPIOB->ODR = 0;																				// (47)
  GPIOC->ODR = 0;																				// (48)
  GPIOD->ODR = 0;																				// (49)
}

static void _init_DMA( void )
{
  static bool initFlag = false;	// To check if it's already initialized!
  if(initFlag == true)		// if it's been initialized
    {
      return;				// simply return from the function
    }

  DMA1_Stream5->CR |= (	DMA_SxCR_CHSEL_1 |			// (2)
  			DMA_SxCR_MINC	 |			// (3)
  			DMA_SxCR_DIR_0	 |			// (4)
			DMA_SxCR_PL_0	 | DMA_SxCR_PL_1 |	// Set the priority very high
			DMA_SxCR_CIRC	 |			// Enabling circular mode
  			DMA_SxCR_PFCTRL				// (5)
  );

  DMA1_Stream5->PAR = &FMPI2C1->TXDR;				// (6)
  DMA1_Stream5->M0AR = &fmp12cBuffer[0];			// (11)
  DMA1_Stream5->NDTR = FMPI2C_BUFF_SIZE;

  //NVIC_SetPriority(DMA1_Stream5_IRQn, 1);			// Set Interrupts priority.
  //NVIC_EnableIRQ(DMA1_Stream5_IRQn);				// Enable Required Interrupts.

  DMA1->HIFCR |= DMA_HIFCR_CTCIF5;				// clearing the DMA flag before enabling the DMA

  DMA1_Stream5->CR |= DMA_SxCR_EN;

  initFlag = true;
}

static void _init_FMPI2C( void )
{
  static bool initFlag = pdFALSE;
  if(initFlag == pdTRUE)
    {
      return;
    }

  //Setting the clock to 400KHz
  FMPI2C1->TIMINGR |= (	(10 << 28) 	|		// (1)
			(1 << 20) 	| 		// (2)
			(1 << 16) 	| 		// (3)
			(1 << 8) 	|		// (4)
			(4 << 0)			// (5)
  );

  //Enable interrupts
  FMPI2C1->CR1 |= (	FMPI2C_CR1_TCIE 	| 	// Transfer Complete interrupt enabled
			FMPI2C_CR1_ERRIE 	| 	// Error detection interrupts enabled
			FMPI2C_CR1_STOPIE	|	// Stop detection (STOPF) interrupt enabled
			FMPI2C_CR1_NACKIE		// Not acknowledge (NACKF) received interrupts enabled

  );

  NVIC_SetPriority( FMPI2C1_EV_IRQn, 1);		// Set Interrupts priority.
  NVIC_EnableIRQ( FMPI2C1_EV_IRQn );			// Enable Required Interrupts.

  _init_DMA();

  FMPI2C1->CR1 |= FMPI2C_CR1_PE;			// (11)

  initFlag = pdTRUE;
}

int32_t FMPI2C1DataTx( uint8_t slaveAddr, uint8_t *data, uint32_t buffSize)
{
  __IO int32_t status = 0;
  uint8_t buffCnt = 0;

  _init_FMPI2C();

  if(buffSize <= FMPI2C_BUFF_SIZE)
    {
      for(buffCnt = 0; buffCnt < buffSize; ++buffCnt)
	{
	  fmp12cBuffer[cnt] = *data++;				// upload the pointed data to buffer and increase one address this way we use that variable as our counter as well
	}
      FMPI2C1->CR2 &= ~FMPI2C_CR2_RELOAD;			// The transfer is completed after the NBYTES data transfer (STOP or RESTART follows).
      FMPI2C1->CR2 |= (buffSize << FMPI2C_CR2_NBYTES_Pos) | 	// The number of bytes to be transmitted/received is programmed there. Note: Changing these bits when the START bit is set is not allowed.
		      FMPI2C_CR2_AUTOEND			// Automatic end mode: a STOP condition is automatically sent when NBYTES data are transferred.
		      ;
    }
  else
    {
      for(buffCnt = 0; buffCnt < FMPI2C_BUFF_SIZE; ++buffCnt)
      	{
      	  fmp12cBuffer[cnt] = *data++;					// upload the pointed data to buffer and increase one address this way we use that variable as our counter as well
      	}
      FMPI2C1->CR2 |= FMPI2C_CR2_RELOAD;				// The transfer is not completed after the NBYTES data transfer (NBYTES is reloaded). TCR flag is set when NBYTES data are transferred, stretching SCL low
      FMPI2C1->CR2 |= (FMPI2C_BUFF_SIZE << FMPI2C_CR2_NBYTES_Pos);	// The number of bytes to be transmitted/received is programmed there. Note: Changing these bits when the START bit is set is not allowed.

      fmp12cMaxNumberOfTransfer = buffSize - FMPI2C_BUFF_SIZE;		// we'll deduct number of bytes that we put into the buffer.
    }

  FMPI2C1->CR1 |= FMPI2C_CR1_TXIE;		// TX Interrupt enable
  FMPI2C1->CR2 |= ((slaveAddr & 0X7F) << 1);	// Slave address (master mode)
  FMPI2C1->CR2 &= ~FMPI2C_CR2_RD_WRN;		// Transfer direction (master mode)
  FMPI2C1->CR2 |= FMPI2C_CR2_START;		// Start generation

  while(1)
    {
      if(fmpi2cStopFlag == true)
	{
	  fmpi2cStopFlag = false;
	  break;
	}
      if(fmpi2cReloadFlag == true)
	{
	  if(fmp12cMaxNumberOfTransfer > FMPI2C_BUFF_SIZE)
	    {
	      for(buffCnt = 0; buffCnt < FMPI2C_BUFF_SIZE; ++buffCnt)
	      	{
	      	  fmp12cBuffer[cnt] = *data++;				// upload the pointed data to buffer and increase one address this way we use that variable as our counter as well
	      	}
	      fmp12cMaxNumberOfTransfer -= FMPI2C_BUFF_SIZE;		// we'll deduct number of bytes that we put into the buffer.
	    }
	  else
	    {
	      FMPI2C1->CR2 &= ~FMPI2C_CR2_RELOAD;			// The transfer is completed after the NBYTES data transfer (STOP or RESTART follows).
	      for(buffCnt = 0; buffCnt < fmp12cMaxNumberOfTransfer; ++buffCnt)
	      	{
	      	  fmp12cBuffer[cnt] = *data++;				// upload the pointed data to buffer and increase one address this way we use that variable as our counter as well
	      	}
	      FMPI2C1->CR1 |= FMPI2C_CR1_TXIE;				// TX Interrupt enable
	    }
	  fmpi2cReloadFlag = false;
	}
    }

  return status;													// (19)
}

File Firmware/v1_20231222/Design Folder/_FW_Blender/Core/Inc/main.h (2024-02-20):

/****************************************************************************************************
*
*   Project Name:       Blender
*   @Brief Description: Blending audio spec with light spectrum
*   File Status:	    DRAFT   (DRAFT , PRELIMINARY, CHECKED, RELEASED)
*
*	File Name:	xxxx.h
*	Version:	01
*	Revision:	01
*	Date:		2023/01/dd
*	License:	Open-source
*	******************************** Project Description *******************************************
*	@Detailed Description: The Blender project's purpose is to extract digitalized sound characteristics
*   like amplitude and frequency, which are transferring through the S/PDIF protocol, and display the amplitude
*   of different frequencies by the dominant color of the input VGA received signal. So the base color will be
*   determined by VGA input, and a spectrum of that color will be displayed over/on the DMX/WS2812 chip. Also,
*   the specification of the sound will be displayed on an OLED, and the sound will be played by a chip that has
*   an integrated DAC in it. The data to DAC will be transferred via the I2S protocol.
*
*	******************************** File Description *******************************************
*	@Detailed Description:
*
*
*
*	*********************************  Hardware Info  **********************************************
*   Name:       _HW_Blender
*   Version:    v1.0
*	*********************************  Processor Info **********************************************
*	Processor:          STM32F446RCT6 32-Bits
*	Clock Frequency:    180.000	MHz
*	RAM/SRAM Size:      128.00	KBytes
*	Flash Size:         256.00	KBytes
*	***********************************  Case Style  ***********************************************
*	Local Variables = camelCase			Global Variables = g_camelCase
*	Headers = SCREAMIN_SNAKE_CASE
*   Macros = SCREAMING_SNAKE_CASE
*   Const Variables = SCREAMING_SNAKE_CASE
*	Functions = PascalCase				Initialize Functions = _lower_case
*	Struct = lower_case					Struct.members = camelCase
*	Enum = lower_case					Enum Members = SNAKE_CASE
*	Pointer Variables = p_camelCase
*	*********************************** Contact Info ***********************************************
*	Author: Siavash Taher Parvar
*	Github: www.github.com/Mend0z0
****************************************************************************************************/

#ifndef __MAIN_H
#define __MAIN_H

#ifdef __cplusplus
extern "C" {
#endif
/****************************************************************************************************
****************************       HEADERS DECLARATION       ****************************************
*****************************************************************************************************/
#include "stm32f446xx.h"
#include "stdbool.h"
#include "STM32F4xx.H"

/*	FreeRTOS Libraries	*/
#include "FreeRTOS.h"
#include "task.h"
#include "queue.h"
#include "semphr.h"

#include "isr.h"
#include "_drv_dmx.h"
#include "_drv_ws2812.h"
#include "_drv_peripherals.h"
#include "_drv_pam8003.h"
#include "_drv_ssd1306.h"

/****************************************************************************************************
****************************        MACRO DECLARATION         ***************************************
*****************************************************************************************************/

/****************************************************************************************************
****************************   DEFINED VARIABLES DECLARATION    *************************************
*****************************************************************************************************/
#define	LED_IND_PIN		GPIO_ODR_OD2
#define	LED_IND_PORT	GPIOD->ODR

#define	EXT_LDO_EN_PIN	GPIO_ODR_OD0
#define	EXT_LDO_EN_PORT	GPIOC->ODR


/****************************************************************************************************
**************************     GLOBAL FUNCTIONS DECLARATION      ************************************
*****************************************************************************************************/
void Error_Handler(void);


#ifdef __cplusplus
}
#endif

#endif /* __MAIN_H */

/****************************************************************************************************
*	Revision History (Description (author, date: yyyy/mm/dd))
*
****************************************************************************************************/

/*                                 FUNCTION DECLARATION TEMPLATE                                   */
/****************************************************************************************************
*   @Brief Description:
*
*	************************************************************************************************
*	Function Name:
*	Function Parameters:
*	Function Return Type:
****************************************************************************************************/
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

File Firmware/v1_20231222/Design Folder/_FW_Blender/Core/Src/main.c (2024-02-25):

/****************************************************************************************************
*
*   	Project Name:       Blender
*   	@Brief Description: Blending audio spec with light spectrum
*   	File Status:	    DRAFT   (DRAFT , PRELIMINARY, CHECKED, RELEASED)
*
*	File Name:	main.c
*	Version:	01
*	Revision:	01
*	Date:		2024/02/20
*	License:	Open-source
********************************* Project Description *******************************************
*		@Detailed Description: The Blender project's purpose is to extract digitalized sound characteristics
*   	like amplitude and frequency, which are transferring through the S/PDIF protocol, and display the amplitude
*   	of different frequencies by the dominant color of the input VGA received signal. So the base color will be
*   	determined by VGA input, and a spectrum of that color will be displayed over/on the DMX/WS2812 chip. Also,
*   	the specification of the sound will be displayed on an OLED, and the sound will be played by a chip that has
*   	an integrated DAC in it. The data to DAC will be transferred via the I2S protocol.
*
********************************* File Description *******************************************
*	@Detailed Description:
*
*
**********************************  Hardware Info  **********************************************
*  	Name:       _HW_Blender
*   	Version:    v1.0
**********************************  Processor Info **********************************************
*	Processor:          STM32F446RCT6 32-Bits
*	Clock Frequency:    180.000	MHz
*	RAM/SRAM Size:      128.00	KBytes
*	Flash Size:         256.00	KBytes
************************************  Case Style  ***********************************************
*	Local Variables = camelCase			Global Variables = g_camelCase
*	Headers = SCREAMIN_SNAKE_CASE
*   	Macros = SCREAMING_SNAKE_CASE
*   	Const Variables = SCREAMING_SNAKE_CASE
*	Functions = PascalCase				Initialize Functions = _lower_case
*	Struct = lower_case					Struct.members = camelCase
*	Enum = lower_case					Enum Members = SNAKE_CASE
*	Pointer Variables = p_camelCase
************************************ Contact Info ***********************************************
*	Author:	Siavash Taher Parvar
*	Github: github.com/Mend0z0
****************************************************************************************************/

/****************************************************************************************************
****************************       HEADERS DECLARATION       ****************************************
*****************************************************************************************************/
#include "main.h"

/****************************************************************************************************
****************************   GLOB. VARIABLES DECLARATION    ***************************************
*****************************************************************************************************/

/****************************************************************************************************
****************************   CONST VARIABLES DECLARATION    ***************************************
*****************************************************************************************************/


/****************************************************************************************************
***********************     STATIC/LOCAL FUNCTIONS DECLARATION      *********************************
*****************************************************************************************************/
void defaultTask( void *pvParameters );

/****************************************************************************************************
****************************         GLOBAL FUNTIONS         ****************************************
*****************************************************************************************************/

/****************************************************************************************************
****************************         STATIC FUNTIONS         ****************************************
*****************************************************************************************************/
int main(void)
{
  /* 	----------------------   		MCU Configuration				----------------------------
	----------------------   Initialize all configured peripherals  ----------------------------*/
  _init_Peripherals();
  /*NVIC_EnableIRQ(SysTick_IRQn);*/				// Enable Interrupts.
  NVIC_EnableIRQ(FMPI2C1_EV_IRQn);			// Enable Required Interrupts.
  NVIC_EnableIRQ(USART1_IRQn);			// Enable Required Interrupts.
  NVIC_EnableIRQ(TIM3_IRQn);				// Enable Required Interrupts.
  NVIC_EnableIRQ(DMA1_Stream5_IRQn);			// Enable Required Interrupts.
  NVIC_EnableIRQ(DMA2_Stream7_IRQn);			// Enable Required Interrupts.

  /* ----------------------   	  Modules Configuration 			----------------------------*/
  SET_BIT( EXT_LDO_EN_PORT, EXT_LDO_EN_PIN);	//Enable the LDO power to turn the modules on
  _init_PAM8003();
  //Each module init will be a task...

  xTaskCreate( defaultTask,	// Pointer to the function that implements the task.
	       "defaultTask",	// Text name for the task.
	       128,		// Stack depth.
	       NULL,		// This example does not use the task parameter.
	       1,		// This task will run at priority 1.
	       NULL		// This example does not use the task handle.
  );
  /*
  xTaskCreate( 	_init_DMX, 	// Pointer to the function that implements the task.
		"DMX", 		// Text name for the task.
		200,		// Stack depth.
		NULL,		// This example does not use the task parameter.
		2,		// This task will run at priority 2.
		NULL		// This example does not use the task handle.
  );

  xTaskCreate(	_init_WS2812, 	// Pointer to the function that implements the task.
		"WS2812", 	// Text name for the task.
		500,		// Stack depth.
		NULL,		// This example does not use the task parameter.
		2,		// This task will run at priority 2.
		NULL		// This example does not use the task handle.
  );*/

  //xTaskCreate( 	_init_SSD1306, 	// Pointer to the function that implements the task.
  //			"SSD1306", 		// Text name for the task.
  //			5000,		// Stack depth.
  //			NULL,		// This example does not use the task parameter.
  //			4,			// This task will run at priority 2.
  //			NULL		// This example does not use the task handle.
  //		);
  /* Start the created tasks running. */
  vTaskStartScheduler();

  while (1)
    {
      //defaultTask( NULL );
    }
}
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

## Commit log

2023-09-30 Adding file structure
    [_ProjectTemplate_.kicad_sch]
2023-10-07 Initial design files
    [[02] - BLOCK DIAGRAM.kicad_sch, [03] - MCU.kicad_sch, [04] - TOSLINK RXTX.kicad_sch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]
2023-12-20 Improving the file structure and documentation
    [[02] - BLOCK DIAGRAM.kicad_sch, [03] - MCU.kicad_sch, [03] - MICROCONTROLLER.kicad_sch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]
2023-12-22 More update for hardware part
    [[03] - MICROCONTROLLER.kicad_sch, [04] - TOSLINK RXTX.kicad_sch, [0501] - VIDEO SIG BUFF.kicad_sch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]
2023-12-22 Firmware update
    [_PNP_Blender-all-pos_v1.0.csv]
2023-12-29 Updating README.md
    [_HW_Blender.kicad_pcb]
2024-01-04 Updating file and folder structure
    [[02] - BLOCK DIAGRAM.kicad_sch, [03] - MICROCONTROLLER.kicad_sch, [04] - TOSLINK RXTX.kicad_sch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]
2024-01-07 Updating Library
    [[03] - MICROCONTROLLER.kicad_sch, [04] - TOSLINK RXTX.kicad_sch, [0501] - VIDEO SIG BUFF.kicad_sch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]
2024-01-08 Adding sys block diagram
    [_HW_Blender.kicad_pcb]
2024-01-15 Top assembled picture has been added
2024-01-16 Updating assembled pictures
2024-01-23 Update [03] - MICROCONTROLLER.kicad_sch
    [[03] - MICROCONTROLLER.kicad_sch]
2024-01-25 Working on Peripheral driver...
2024-01-25 Working on peripheral drivers
2024-01-28 Working on peripherals driver
2024-01-28 Updating 3D components
    [[03] - MICROCONTROLLER.kicad_sch, [04] - TOSLINK RXTX.kicad_sch, [05] - BUFFERED VGA INPUT.kicad_sch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]
2024-01-28 Adding 3D File
    [Connector, XLR3, Female, Chassis - Switchcraft-D3FB.igs, Connector, XLR3, Female, Chassis - Switchcraft-D3FB.stp, Connector, XLR3, Female, Chassis - Switchcraf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]
2024-01-28 Finishing up on Mechanical CAD
    [NC3FD-LX.stp, _HW_Blender.kicad_pcb, _MECH_Blender.cfg]
2024-01-28 Done with mechanical Designing
    [_MECH_Blender.cfg]
2024-01-29 Working on the peripheral drivers
2024-01-30 Changes to CAD file structure and add some todo work
    [Connector, XLR3, Female, Chassis - Switchcraft-D3FB.igs, Connector, XLR3, Female, Chassis - Switchcraft-D3FB.stp, Connector, XLR3, Female, Chassis - Switchcraf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]
2024-02-01 Working on peripheral driver
2024-02-03 Improving the 3D file
    [3.7v li-ion 500mah Battery.step, M2.5 Nut.STEP, M3_Countersunk_Screw_5.IGS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]
2024-02-03 Improving CAD model
    [_MECH_Blender.cfg]
2024-02-07 Some progress on drivers (modules and peripherals)
2024-02-08 Progress on module drivers
2024-02-08 Some progress for SSD1306 driver
2024-02-08 More progress on modules' driver
2024-02-12 DAC and PAM8003 driver has been done
2024-02-12 Interrupt driver is done
2024-02-17 Resorting the folder structure
    [[02] - BLOCK DIAGRAM.kicad_sch, [03] - MICROCONTROLLER.kicad_sch, [04] - TOSLINK RXTX.kicad_sch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]
2024-02-18 Improving the 3D view and Adding the CAD view
2024-02-18 Improvement in folder structure
    [3.7v li-ion 500mah Battery.step, Connector, XLR3, Female, Chassis - Switchcraft-D3FB.igs, Connector, XLR3, Female, Chassis - Switchcraft-D3FB.stp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]
2024-02-21 Working on FreeRTOS tasks and configurations
    [[03] - MICROCONTROLLER.kicad_sch]
2024-02-21 More progress on fixing FreeRTOS problem
    [ISR.c, _drv_WS2812.c, _drv_peripherals.c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]
2024-02-22 The tick clock has been fixed and corrected.
    [main.c, main.h]
2024-02-25 Working on DMX driver
2024-02-27 Working on SSD1306 driver
